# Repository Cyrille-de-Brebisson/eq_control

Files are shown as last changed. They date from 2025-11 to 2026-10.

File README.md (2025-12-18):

# eq_control

Eq control is an esp32/arduino based equatorial telescop mount controler system.
This also has an additional focuser controler (or rotator if you want, but focus is the most useful)

This system was originally designed for an EQ3, but has been sucessfully used on EQ5 and other az mounts.

It consist of a CPU that can control 3 stepper motors for RA, Dec and focus, a LCD and a keyboard.

It can be used "in hand" as an offline controler.
It can be connected to a computer with Ascom or Alpaca for more complex astro (like astro photography).
The controler is a 6x7x1.7cm box which does everything!

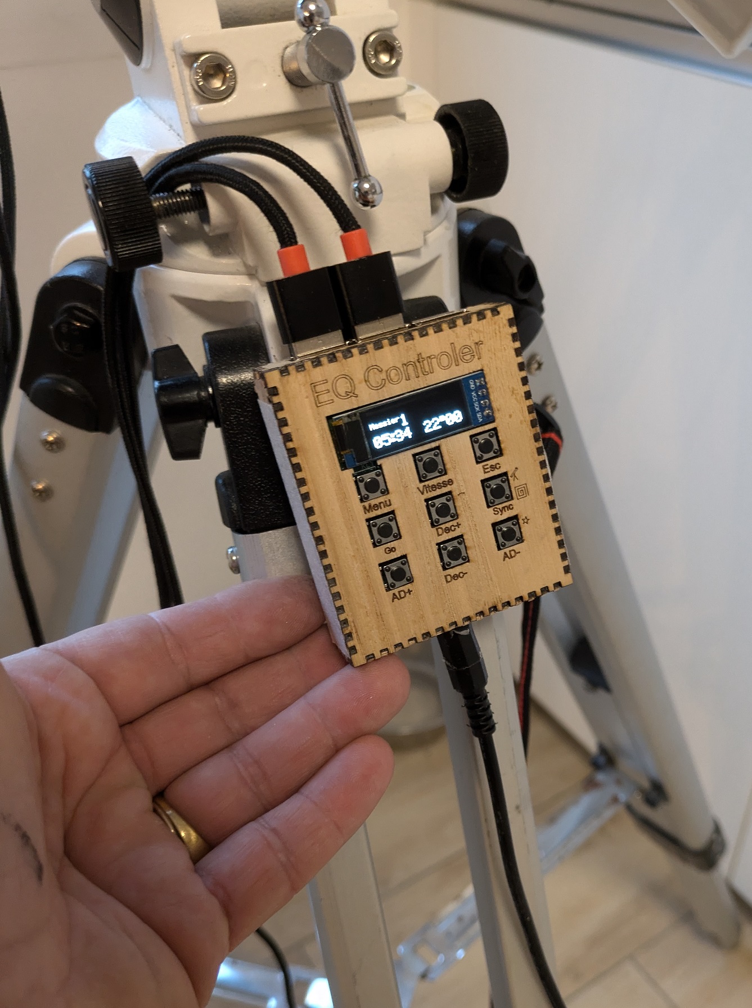
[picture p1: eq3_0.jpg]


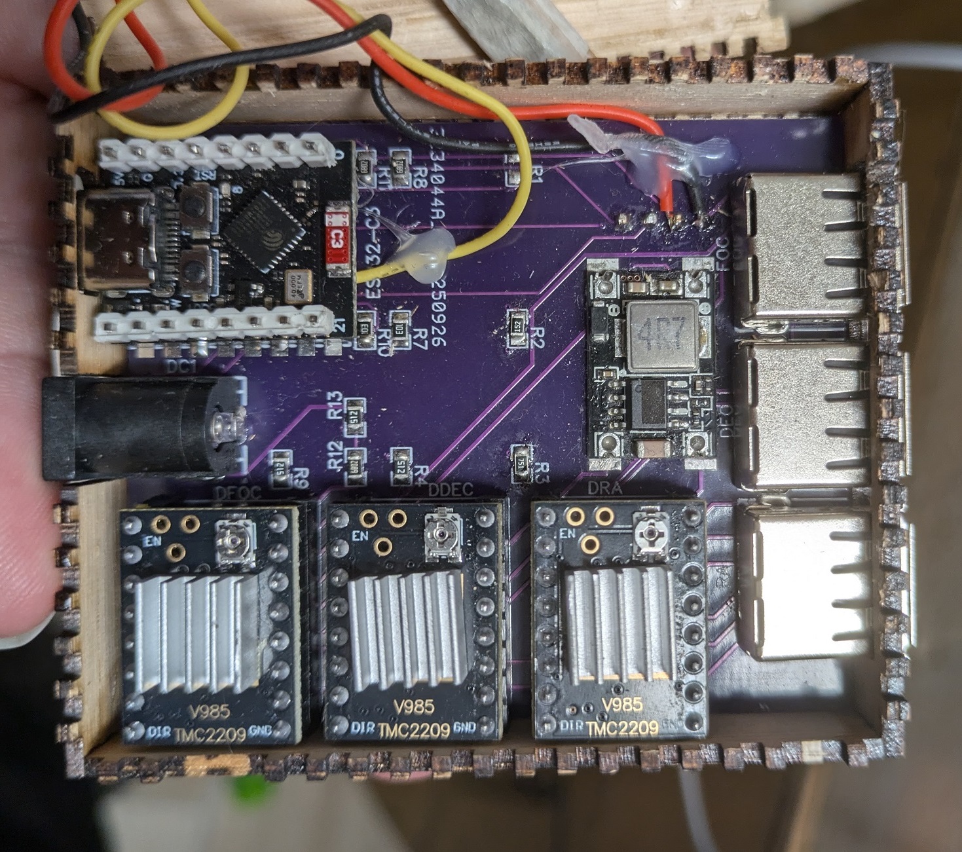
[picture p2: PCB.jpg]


# Brief history

This project started on arduino Nano. This was never released at large, but I have given a number of boards to various persons and I still own a number of them. As a result I need to continue supporting them.

Hence the code here continues support for these old boards which you will find in Firmware\eqControl_Ino

# Directory structure, Aka: Where to find stuff
## Software

If using esp32, you will open the Firmware directory using visual studio code and esp-idf. This uses the same .ino code as a #include!

in the Firmware\windows directory you will find a windows solution that uses once again the same code and can be used for debugging.

the Ascom directory contains the Ascom driver for the system (need visual studio and ascom tools installed)

## Hardware
HW project can be found here:  https://oshwlab.com/cyrille.de.brebisson/sheet_copy_copy_copy_copy_copy_copy_copy_copy

The Hwardware and mechanicals directory has the Gerber and schematics.
I still need to put the files for making the laser cut box

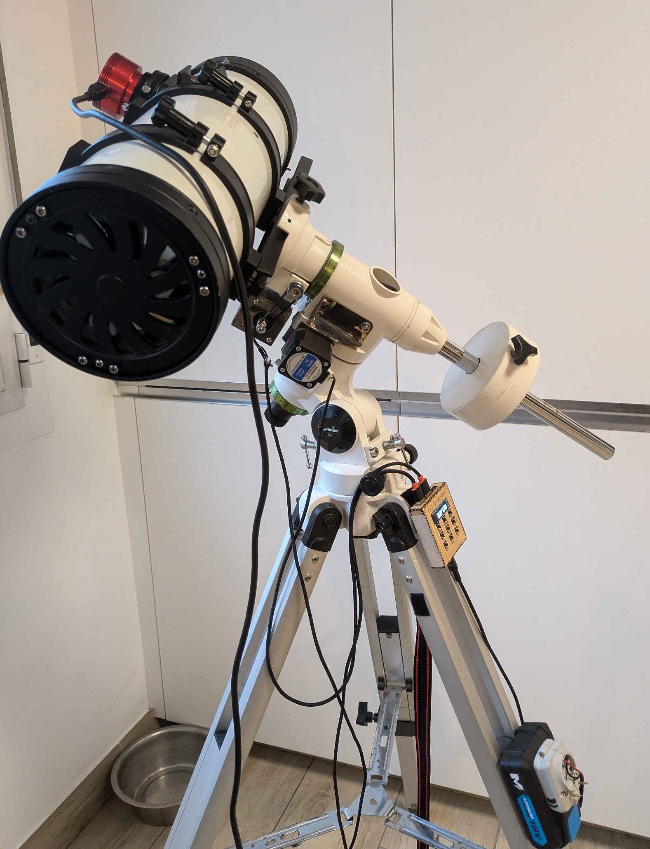
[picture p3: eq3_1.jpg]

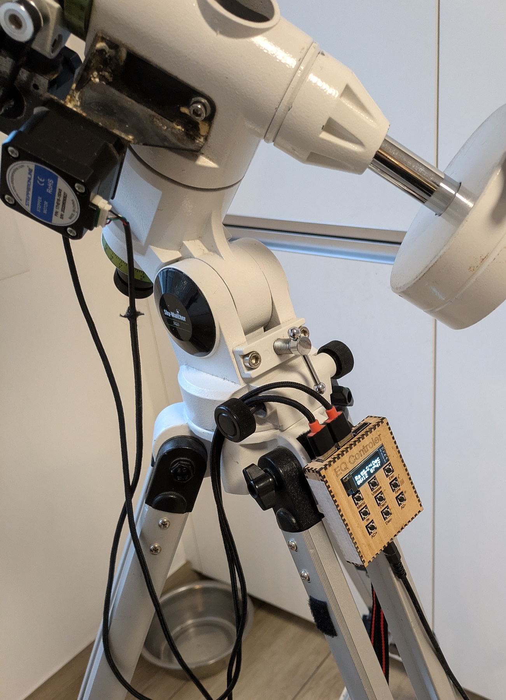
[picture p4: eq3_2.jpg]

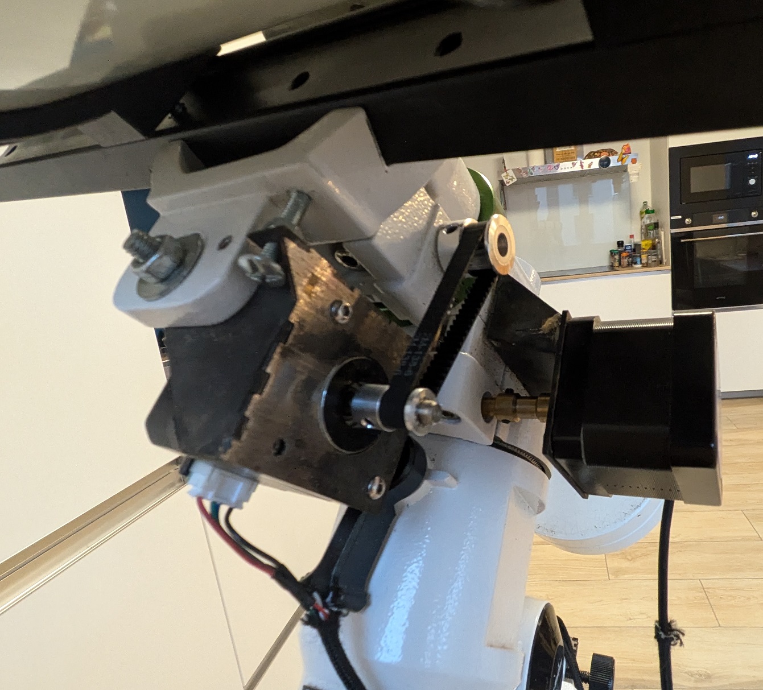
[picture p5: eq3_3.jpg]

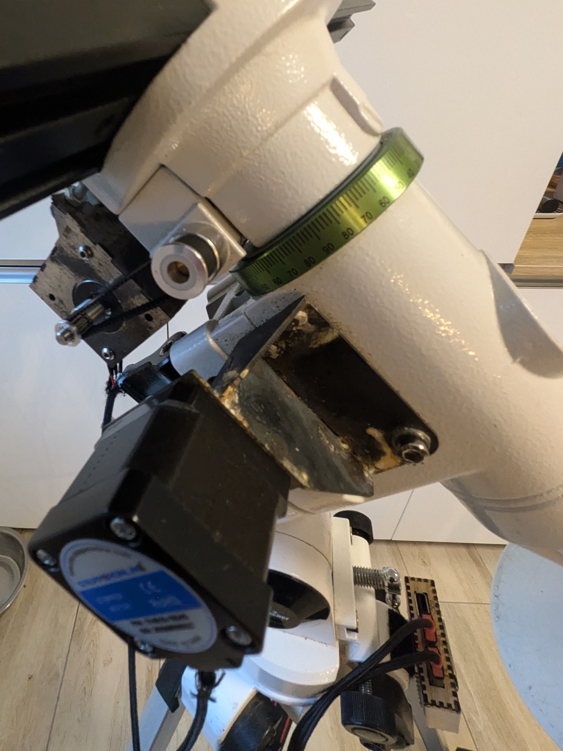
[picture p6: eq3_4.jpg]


# Licence
All content of this repository is copyright Cyrille de Brébisson
Contact me if you want to use all or part of it.
Most likely I will say yes unless it is for commercial use at which point... we can discuss

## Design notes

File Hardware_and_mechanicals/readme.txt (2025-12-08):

box esp32 files is a drawing for the "box" for the controler.
It is desinged to be laser cut out of 2mm thick wood or plastic.

eq3_5 dec.dxf is the declinaison motor holder for both EQ5 and EQ3. It is desinged to be laser cut out of 1.5mm thick metal. There is one bend to do, an "assembly" and a weld. Note that it is made as "one part" which will need to be separated in 2 at a tab as it reduces the costs for me here..

eq5ra.dxf is the eq5 ra motor holder. It also needs a "bend" and is also designed to be laser cut out of 1.5mm steel. Note that you will need to dril and tap 2 M4 holes in your mount to use it.

eq3_ra.svg is the EQ3 ra holder. Here again a bend and 3 peices to separate and place together.

PCB, schematics and Gerbers are the pure HW files.

About the HW design.

An esp32C3 super mini is the core.

The 9 key keyboard is read by the CPU using ADC and a resistance ladder due to the IO limitation.

The same ADC is used to read external power level using a divider bridge.

5V to ESP is provided using a DC-DC board for high power efficiency (regulator can drop significant power, especially if dropping from 20V to 5V).

3 TMC2209 stepper drivers are used to drive the motors. They are driven using the step pin and serial communication.

A 0.96 I²C OLED 128*32 LCD does the display (prefer blue, less agressive for the eyes)

Connection to the motors is done using USB2 connectors cause they are cheap and good connectors.
It is also easy to find USB cables, cut the device side and repurpose them for motor connection.

A 5.5x2.1 barrel connector is used for external power. Use a 12-15V, 1A power source or a 15V USB-C to barrel adaptor for power.

I usually place the ESP and drivers on low profile "carriages" to make them replacable in case of...

Appart from the drivers which are relatively expensive and for which you need 2 or 3, all the rest is dirt cheap. And the PCB will come as a 5 pack. So I advise that you take enough material to build at least 2 in case of!

Parts (all sourced on ali express)
Esp32C3 super mini board (<3 euros): https://fr.aliexpress.com/item/1005009776606859.html
9 6x6 low profile push buttons, SMT (<1 euro, usually by 20 packs): https://fr.aliexpress.com/item/1005003163947039.html
3 TMC2209 (~2.6 euros per driver): https://fr.aliexpress.com/item/1005009299841291.html
0.96 OLED 128*32 LCD (<2 euros): https://fr.aliexpress.com/item/1005008918700196.html
10k, 1.5k, 750R, 68K and 5.1K 0805 resistances will be needed (but yhou could probably get by without the 68K and 5.1K ones using 10k and 1.5k instead for the power divider bridge).: https://fr.aliexpress.com/item/1005004765509774.html
3x 100µF capacitors: https://fr.aliexpress.com/item/1005004506467517.html
header: Use low profiles ones! https://fr.aliexpress.com/item/1005004122312694.html
USB connectors (1.5euros by 10): https://fr.aliexpress.com/item/4001141222647.html
5.5 2.1 DC connecteor PCB: https://fr.aliexpress.com/item/32839712664.html

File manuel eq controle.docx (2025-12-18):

# Manuel d’utilisation « EQ Controleur »

Conceptions Cyrille.de.brebisson@gmail.com

## Introduction

L’EQ Controleur (contrôleur pour montures équatoriales, originellement EQ3 et EQ5, mais utilisable sur plein d’autres montures) a été conçu dans dans l’optique :

- De créer un contrôleur le plus simple possible à utiliser
- De créer un contrôleur par cher pour une EQ3
- De créer un contrôleur utilisable en mode manuel
- De créer un contrôleur permettant de faire de l’asto-photo

La première section de ce manuel assume que vous avec un EQ Controleur installé sur votre monture et désirez l’utiliser en mode manuel.

La deuxième section étudie les possibilités offertes si vous êtes connecté à un PC.

La troisième section explique la partie configuration.

## Utilisation « Manuelle »

### Démarrage

Sortez votre monture, alignez là (grossièrement) vers le nord. Utilisez une boussole (une vraie ou celle de votre portable), essayez de la mettre à la bonne inclinaison (selon votre latitude). Si c’est la nuit, vous pouvez vous aider d’un laser que vous insérez dans l’axe polaire et vous bougez la monture pour pointer Polaris.

Installez votre optique sur la monture et équilibrez-la en RA (Right Assention où ascension droite) et en DEC.

Pointez le télescope vers le nord avec le contrepoids « vertical ».

Branchez le contrôleur sur une alim entre 9 et 20V (12 à 15 est impec) 20W.

Notons que dorénavant je parlerais de 12V pour parler ce cette alimentation quel que soit la valeur réelle.

Il va s’allumer. Votre télescope est en mode suivit immédiatement.

### Mouvements basiques

Utilisez les touches dec+/dec- et ra+/ra- pour bouger le télescope.

Pressez la touche vitesse pour « cycler » entre les différentes vitesses possibles, de une minute d’arc par seconde a 4° par seconde. Apprenez la place de ces 5 touches « par cœur » car vous les utiliserez en regardant à l’oculaire !

Notez que l’affichage vous indique la position du télescope ainsi que la vitesse (en petit, désolé !)

Vous pouvez des à présent pointer le télescope sur un objet et le regarder…

Disons que l’objet en question est l’étoile Arcturus.

### Menu étoiles et synchronisation

Appuyez sur la touche « menu » jusqu’à ce que l’affichage indique :

Ou tout autre nom d’étoile précédé par ce « dessin » d’une étoile.

Utilisez les touches RA+/RA- et DEC+/DEC- pour « séléctionner » arcturus dans la lise. RA- passe à l’étoile suivante, RA+ à la précedente. Dec+/Dec- avancent de 10 en 10 permétant d’aller plus vite.

Selectionner Arcturus

Puis appuyez sur la touhce « Sync ». Vous venez d’apprendre au télescope « ou il est ».

Vous pouvez maintenant aller séléctionner une autre étoile, par example Vega, et appuyer sur la touche « Go » et le téléscope deverais se déplacer sur Vega !

Plus votre mise en station est correcte, plus Arcturus était bien centré dans votre oculaire et plus votre monture est bonne méchaniquement, plus ce déplacement sera correct et précis !

### Messier, Ngc et Cadwell

Vous avez probablement repéré en appuyant sur la touche menu que le système vous proposait d’autres options.

En effet, vous pouvez selectioner tout objet Messier, Cadwel et les 740 Ngc les plus visibles.

Comme les étoiles, ces objets sont utilisable pour « sychroniser » le télescope, où pour faire un goto (déplacer le télescope) de la même manière qu’avec les étoiles.

moins d’avoir un méga télescope, et dans ce cas que faites vous avec ce petit système tout simple, cela deveais largement sufire !

### Escape et spirale

2 autres touches sont importantes.

La touche Esc(ape) permet de ressortir d’un menu et de revenir à l’ecran principal.

Elle arréte aussi tout mouvement en cours du télescope.

La touche Sync, quand on est sur l’ecran pricipal vas faire décrire une spiralle (bon, une spirale carrée, c’était plus facile a programmer) au télescope. Notons que la vitesse et l’espacement entre les spirales vont être d’autant plus grandes que vous avez spécifié une grande vitesse. Cette touch est TRES utilie quand on est proche de l’objet convoité mais qu’il n’est pas dans l’oculaire.

Si c’est le cas, le centrer, retourner dans le menu associé et refair eun sync permet de « corriger » le télescope.

Si votre télescope n’est pas parfaitement mis en station, un « go » dans une région très différente résultera en un télescope qui peut être à quelques degrés de votre cible. Refaite un sync sur une étoile dans la zone et vous « recentrerez » le télescope dans cette zone.

### Planètes

Finissons par l’écran planètes qui est un peu plus compliqué.

En effet, pour pointer une planète, il faut savoir ou elle est, et pour ce faire, il faut connaitre la date. Mais le CPU n’a pas d’horloge, il vas donc falloir la lui indiquer !

Ici 01/01/23 (format J, M, A). Notez le 01 souligné.

Les touches RA+/RA- permettent de changer l’information soulignée. Les touches dec+/dec- permettent de changer la valeur. Sélectionnez donc la date du jour, puis séléctionnez la planette (toujours avec dec+/-). Utilisez les touches Sync et Go comme avec les étoiles et autres objets pour synchroniser le telescope ou aller sur l’objet.

Note : Je n’ai jamais bien testé cette partie du soft et je ne connais pas la précision réele de mes calculs ! à utiliser en faisant attention !

### Note sur le retournement au méridien

Une monture equatoriale alemande doit changer le télescope de coté lorsque sa dirrection de visée traverse le méridien.

Généralement vous verrez ce mouvement « bizard » lors des operations de « aller vers », ou goto. Mais si vous observez un objet longtemps, le télescope peu effectuer ce retournement par lui-même. Ce retrounement arrive lorsque l’axe télescope-contre-poid dépasse l’horizontale.

Pour que ce retournement se passe bien, il faut que le télescope sache ou est l’horizontale de l’axe télescope-contre-poid (axe RA). C’est pour cela qu’il est important de démarrer le télescope avec cet axe pointant « vers le bas », car le système se « souviens » de cette position pour savoir ou se trouve l’horizontale.

C’est pour cela qu’il est important de ne pas faire de mouvement en RA en bougant le télescope en desserant les freins, mais de toujours utiliser la raquette.

### Touches spéciales

Maintenir la touche Esc pressée, puis appuyer sur la touche RA- (en bas a droite) à pour effet de changer la vitesse de suivit sidérale. Le système supporte les vitesses Sidérales, Lunaires, Soleil et King. Chaque appui sur RA- avance d’un cran.

Maintenir la touche Esc pressée, puis appuyer sur la touche GO reset l’écran. A utiliser si l’affichage plante.

Maintenir la touche Esc pressée, puis appuyer sur la touche RA+ (en bas a gauche) reboot le système. Attention, le télescope pense alors être en position de départ !

Maintenir la touche Esc pressée, puis appuyer sur la touche dec+ desactive le retournement au méridien. A utiliser avec parsimonie et en faisant attention.

Maintenir la touche Esc pressée, puis appuyer sur la touche Sync à pour effet de changer la dirrection de l’axe delta. Si il y a eu un problème d’initialisation cela peux résoudre ce problème. Mais sinon vous ne devriez pas à avoir a utiliser cette combo.

### Derniers détails

L’écran de base indique les coordonées RA/DEC actuelles.

Il indique aussi la vitesse (Spd) de déplacement que vous savez maintenant changer.

Il indique la vitesse de suivit. Ici Sidéral. Que vous savez aussi changer !

Le dessin a coté de la vitesse indique si le telescope est a l’est ou a l’ouest de la monture. Notez que vous retrouverez ce dessin dans les selections d’objets type Messier, Ngc… Si il est affiché, cela indique que l’objet en question est de l’autre coté du méridien par raport a la position actuelle du télescope.

Pour finir si la vitesse est « barrée », cela indique que la monture n’est pas allimentée en 12V, mais seulement via la prise USB, ce qui n’est pas suffisant pour faire bouger les moteurs !

## Utilisation assistée par ordinateur

C’est une fois connectée à un ordinateur que le système montre toute sa puissance.

### Connection filaire, driver Ascom

Il y a 2 connections possibles, la connexion filaire (conseillée car plus stable), MAIS qui est de temps en temps problématique.

En effet la connexion USB est souvent mal faite sur les ordinateurs. Et quand on alimente la monture en 12V, il se peut que le 0V (masse) de l’alimentation ne soit pas équivalent au 0V de l’USB. Mais sur la raquette, les 2 0V sont les mêmes. Sur certains ordinateurs cela peut poser problème. De temps en temps l’ordre de connexion change les choses. Soit il faut d’abord connecter le 12V, puis l’USB, soit dans le sens inverse. Ecoutez le PC et les « bit bip » de connexion USB pour avoir une bonne idée de ce qui se passe.

### Installation Ascom

Il va vous falloir installer le logiciel, Vous allez devoir installer le système Ascom, puis copier les 4 fichiers ASCOM.BrebissonV1.exe, issposdll.dll iss.wav et power.wav dans le répertoire C:\Program Files (x86)\Common Files\ASCOM Puis, ouvrerez une invite ligne de commande (touche windows +R, tapez cmd, enter), aller dans le répertoire ascom en tapant « cd " C:\Program Files (x86)\Common Files\ASCOM" » enter

Puis taper : « ASCOM.BrebissonV1 /register »

Cela à pour effet d’enregistrer ce programme dans le système Ascom.

Accessoirement, vous pouvez cliquer sur le fichier install.bat après avoir dézipé les fichiers dans un repertoire temporaire.

Lancer ASCOM.BrebissonV1.exe et vous verrez la fenètre qui est quelques pages plus loin.

### Connection « com »

La première chose à faire vas être de « connecter » le programme a votre raquette que vous aurez branché sur votre ordinateur via le port USB. Cela se fait via ce que l’on appelle un port « com ».

Dans tous les cas il va vous falloir « trouver » quel est le port COM utilisé par votre raquette.

Si le logiciel de contrôle à été lancé APRES que vous ayez connecté la raquette au PC, il va vous falloir appuyer sur le bouton « scan coms » pour recréer la liste des ports com qui est affiché à gauche du dit bouton. Mon conseil est de regarder la liste, de scanner les coms, et de re-regarder la liste. Le « nouveau » com est celui de votre raquette !

Si le logiciel à été lancé avant… vous pouvez essayer les divers coms, ou alors déconnecter votre raquette, rescanner la liste et procéder comme indiqué ci-dessus.

Puis appuyer sur le bouton « connect » qui deviens alors « disconnect » pour que le programme commence à parler à la raquette…

### La fenêtre principale

S’affiche la position actuelle du système. Notons que dans les premières versions la raquette vas redémarrer et perdre sa position ! Si le télescope était en position « nord », le PC qui connais l’heure locale vas, en utilisant les données de positions indiquées dans le setup calculer la position en AD automatiquement. Si votre télescope est parfaitement aligné en position nord, vous êtes donc a peu près synchronisé.

La partie « mount » indique la position actuelle. La touche Copy vas la copier dans les 2 boites d’édition dessous qui permettent de faire un goto ou sync.

Les touches goto et sync permettent de faire un goto ou sync à la position indiquée dans les 2 boites de texte sous la position actuelle.

Le bouton stop arête tout mouvement du télescope.

« Mount East »/ « Mount West » correspond à l’appui sur les touches Esc puis Sync de la raquette. Cela change la dirrection de l’axe delta. Si il y a eu un problème d’initialisation cela peux résoudre ce problème.

Le bouton flip enable/flip disable permet d’arrêter le retournement au méridien. Cela fait que le télescope peu se retrouver la tête en bas ! A utiliser quand vous savez ce que vous faites !

Notons l’indication « flip in : 6 :23 » qui indique qu’il reste 6h23 minutes avant un retournement au méridien (si le télescope reste pointé sur le même objet).

Dessous, vous avez une drop box qui indique la vitesse de déplacement sidéral.

Vers la droite, 4 touches permettent de bouger le télescope à la vitesse indiquer juste au-dessus.

En bas de la zone, Park/unPark permet de « parker » la monture, c’est-à-dire de la remettre en position « nord » et d’arrêter le mouvement sidéral. Unpark se contente de relancer le mouvement sidéral.

Flip force un retournement au méridien. A utiliser quand le télescope est en bout de course pour forcer les choses a un moment opportun pour vous.

isNorth vas « assumer » que le télescope pointe au nord et forcer les coordonnées correctement.

Et finalement les boutons +90° et -90° permettent de forcer la monture a faire 90° en plus ou moins en RA. C’est très utile lors de la mise en station avec sharpcap ou il faut faire décrire 90° au télescope !

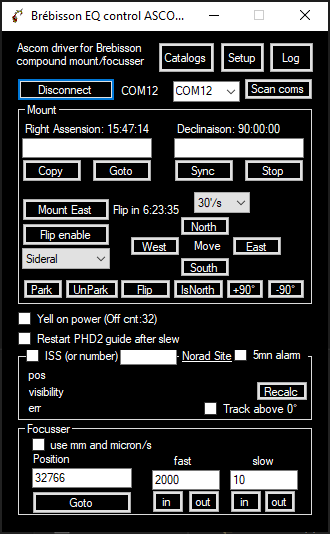
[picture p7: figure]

Le checkmark « Yell on power” vas faire que le programme va jouer le fichier son « power.wav » si il détecte une perte de 12V. Très utilise si on est en nomade sur batteries.

Le checkmark « Restart PHD2 guide after slew” vas faire que PHD2, si il est actif vas être relancé en mode guidage après une opération de goto. Comme PHD2 s’arrête lorsqu’il détecté un mouvement de télescope, cela permet de le relancer automatiquement si votre logiciel de prise de vue ne le fait pas.

### La section ISS !

Sélectionner ISS et le système va se connecter au site du Norad (oui, comme dans WarGames !) et récupérer les données orbitales de l’ISS (ou de tout autre satellite dont vous indiquerez le numéro dans la zone d’édition a côté de ISS. Cliquer sur « Norad site » pour rendre visite au site du Norad et trouver les infos sur les satellites.

Sélectionner 5mn alam pour avoir ma jolie voix vous indiquer que l’ISS vas arriver 5mn avant qu’elle ne dépasse l’horizon.

Vous allez ensuite voir la position de l’ISS en ra/de cet az/alt, suivit d’une indication « NotVisible » (pas visible) et le temps a attendre avant qu’elle ne passe au-dessus de l’horizon. Vous aurez aussi l’indication de la « hauteur » du transit (ici 19°, pas très haut), de la durée (9mn) et de la vitesse max (ici 0.8° / s).

Notons que si le système ne peut pas se connecter au Norad car la ligne est occupée par Matthew Broderick, il utilisera les dernières infos connues.

Sélectionner « Track above 0° » et le système vas suivre l’ISS des qu’elle sera au-dessus de l’horizon !

Pour que cela marche bien il faux mieux préparer le télescope quelques minutes avant (d’où l’alarme). Placez le environ 20° au-dessus de l’horizon dans la zone ou l’ISS vas arriver, faite une synchronisation sur la position pour être le plus précis possible (si vous le faites trop bas la réfraction atmosphérique peux troubler les choses). Puis descendre le télescope proche de l’horizon et attendre.

Quand l’ISS deviens visible, et que vous êtes en mode « track » vous aurez cet écran-là :

La partie importante est la zone d’édition indiquant « Press up/down/right/left to correct. » cliquer dedans et utiliser les touches haut/bas/droite/gauche de votre ordinateur pour envoyer des corrections supplémentaires au système. Cela vous permet de corriger manuellement toute erreur de position.

Le système va tracker l’ISS (ou le satellite) tant qu’il le peut.

Notons que si le satellite va trop vite, il n’y arrivera pas (mais il essayera), plus le satellite sera près du zénith plus il ira vite. LA monture arrivera probablement au méridien a un moment et voudra se retourner ! Si elle y arrive assez vite, elle continuera à tracker… La correction en arc seconde sera indiquée pour info.

Quand vous de-cliquez le bouton track, un log des positions sera ajouté sur le desktop.

### La section Focusser

Ici vous pouvez utiliser l’option focus du contrôleur. En effet ce système est capable, en plus du télescope de contrôler le focus de votre optique si elle est motorisée.

Le checkmark « Use mm and micron” indique si vous voulez travailler en pas, ou en distances réelles.

La position indique la position actuelle en pas (toujours positive) ou en mm (positive ou négative).

Les boutons in/out fast et slow permettent de faire bouger le focusser a une vitesse donnée en pas ou microns par secondes.

## La section setup

Cliquer sur le bouton « Setup » pour entrer dans la section de configuration.

Vous y trouverez les informations sur l’observatoire. Ces infos sont principalement informative et seront utilisé par le logiciel de capture d’image pour régler le plate solve et pour tagger vos photos. La longitude sera utilisée par ce logiciel pour calculer l’heure sidérale (important).

Vous allez ensuite trouver 3 zone similaire des configurations des moteurs pas à pas. Dans tous les cas il va falloir indiquer le nombre de pas maximum, qui correspondront a un tour complet dans le cas des moteurs RA/DEC et de l’amplitude max pour le focusser (notons que celui-ci est limité a 65535 pas).

Il faudra indiquer le nombre de pas max par seconde (la vitesse max en gros) et le temps d’accélération pour arriver a cette vitesse max en ms.

Il vous est aussi possible d’indiquer un baklash. C’est-à-dire un nombre de pas ou d’arc secondes a rajouter sur tout mouvement quant on inverse la direction de mouvement. Cela permet de gérer les jeux mécaniques.

Vous pouvez aussi indiquer le ‘sens’ du moteur via la ckechbox ‘invert’.

Dans le cas du focus, si vous indiquer la taille d’un pas en microns, cela permettra aux meilleurs soft astro (genre Prism) de gérer les choses en mm ce qui peut être très pratique dans certains cas (par exemple los de l’ajout d’un filtre).

Dans le cas du mouvement en RA, vous pouvez indiquer l’amplitude en °. 180° signifie que l’axe RA ne dépassera jamais l’horizontale. Dans la réalité, il est généralement utilisé de permettre un mouvement de 30 minutes à 1h de plus de chaque côté de l’horizontale. 30 minutes de RA étant 7.5°, ajoutons 2*7.5=15° a 180 pour 195°.

Notons la présence d’une aide au calcul de pas en bas. C’est juste une suite de multiplication et de divisions qui vous évite d’avoir à sortir la calculatrice !

Les drivers de type DRV2209 qui équipent mes dernières montures sont en 256 micros pas. La plupart de moteurs pas à pas sont en 200 pas par tours, les EQ3 ont une réduction mécanique de 130 :1 en RA et 65 :1 en dec. Les EQ5 144 :1 sur les 2 axes. Si vous avez des poulies, il va falloir les rajouter via les ‘gear’. Pour finir il y a une division qui permet de calculer la vitesse en pas/s selon ce que vous désirez, et ce que votre monture supporte.

La section guiding permet de configurer le guidage. Donnez la vitesse de guidate en arc" par seconde de contrôle. J’ai ajouté des options pour moduler le contrôle du logiciel de guidage ‘agresivity, qui se multiple a la consigne), pier invert qui inverse la consigne suivant le coté du télescope, invert qui inverse la consigne tout le temps et stop qui bloque le guidage sur un axe. Mais normalement il n’uy a pas lieux d’utiliser ces choses que j’ai ajouté principalement pour faire mes tests..

La section « Time base » est une analyse de la différence entre la théorie et la pratique. Il va analyser la manière dont la raquette et le PC perçoivent le temps et vas permettre (en assumant que le PC est correct) de calculer une correction (en cliquant sur le bouton Auto). Laisser tourner le système au moins 5 minutes avant d’utiliser cette fonction !

On y voit la base de temps PC, la base de temps HW et la différence. On y voit aussi le nombre de pas par seconde en sidéral « envoyés » par le HW et l’erreur.

Les arduinos ont généralement un drift non négligeable. Mais les ESP32 sont très bon et n’ont pas besoin de correction.

Les ESP32 ont un réglage de wifi.

Vous pouvez sélectionner le mode AccessPoint (la raquette est un server wifi), ou « client » ou il se connecte à votre réseau wifi. Indiquez le nom du réseau et le mot de passe. L’adresse IP vous sera indique ici aussi.

Pour finir le bouton « save in HW » vas « écrire » toutes les données dans la raquette (et faire un reboot). Reload from HW permet de recharger les données qui sont dans la raquette si vous avez changé un truc et que vous voulez revenir à la vraie valeur.

Save conf et load conf permettent de sauvegarder une configuration sur PC.

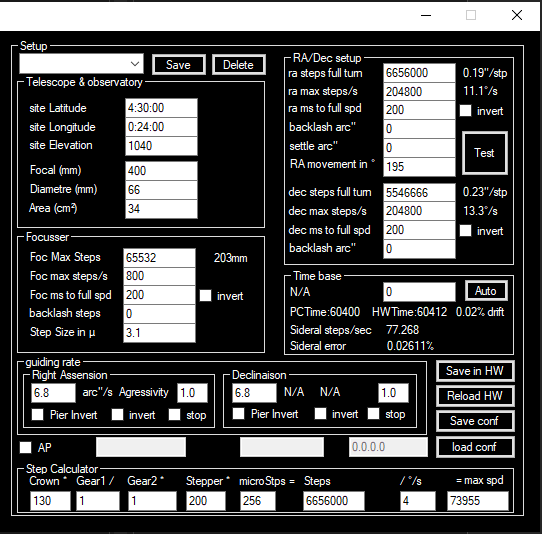
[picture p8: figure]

## La fenêtre Catalogs

Bone encore une chose à moitié faite….

Cliquer sur Messier, Cadwell, Ngs, Stars et planètes pour afficher à droite la liste en question. Sélectionner un des objets et cliquer sur GoTo ou Sync pour faire un Goto ou un Sync. C’est une version ordinateur des menus équivalents de la raquette.

L’écran montre la position du télescope sur la voute céleste. Vous pouvez bouger la vue avec la sourie, et si vous sélectionnez un objet dans cet ecran et qu’il apparait en bas de l’écran, les touches goto et sync permettent les actions habituelles.

Le bouton « OnScope » recentre la vue sur le télescope.

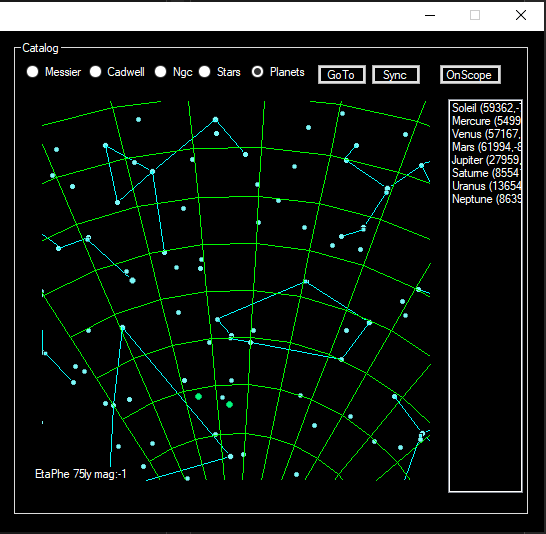
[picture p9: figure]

## La fenêtre « log »

Cliquer sur Log pour voir la fenêtre le log. Vous y trouverez principalement un log de tout ce qui c’est passé au sein de la monture. Les check box « show system », « show ascom »… etc permettent d’ignorer certains évènement qui ne vous intéressent pas.

2 lignes de texte montrent les communications entre la monture et le PC en hexa et en « clair » et permettent de faire un freeze des choses pour étudier les choses en détail (principalement pour faire du débug).

Les 4 touches « pulse guide » permettent d’envoyer des pulsations de guidage. C’est utile pour tester le backlash de la monture de jour sur une cible fixe.

La section moteur indique la position des moteurs en pas et en % de mouvement.

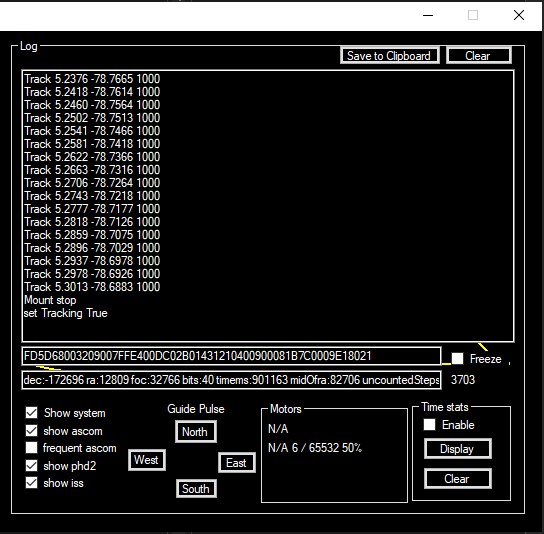
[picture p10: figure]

## Liaison avec Stelarium

Comme ce programme est un driver Ascom il est utilisable pour connecter votre télescope a tout logiciel gérant Ascom tel que Prism, SharpCap, Stellarium ou PHD2.

Je me contenterais d’expliquer l’utilisation dans Stellarium qui est assez complexe tout en étant super utile pour un débutant.

Premièrement, lancer le plugin contrôle télescope. F2 ou configuration window/ Plugins, telescope control (ou controle de telescope), sélectionner « lancer au démarrage). Redémarer stellarium.

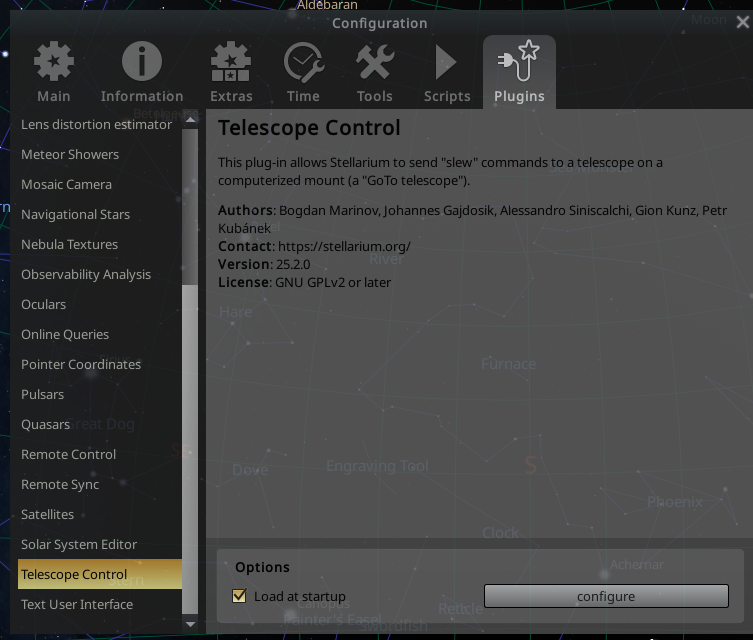
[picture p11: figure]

Cliquer sur ‘contrôle télescope’ qui est maintenant dans la barre d’actoin en bas. « configure telescope » Add new telescope , Ascom, choose ascom telescope, et séléctionner Ascom telecope driver pour BrebissonV1.

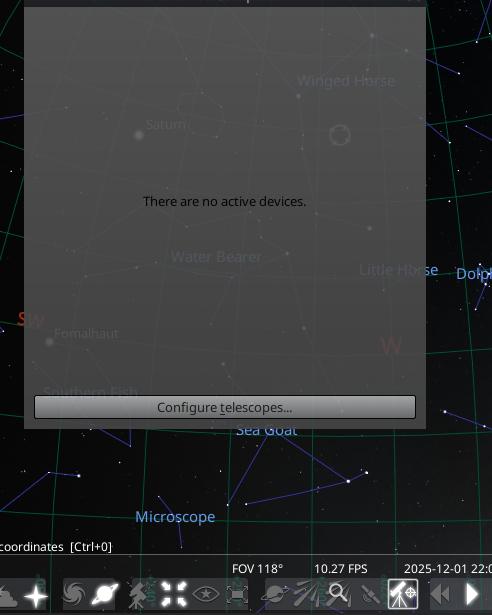
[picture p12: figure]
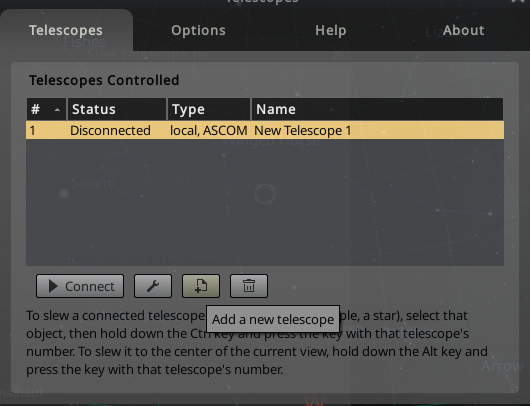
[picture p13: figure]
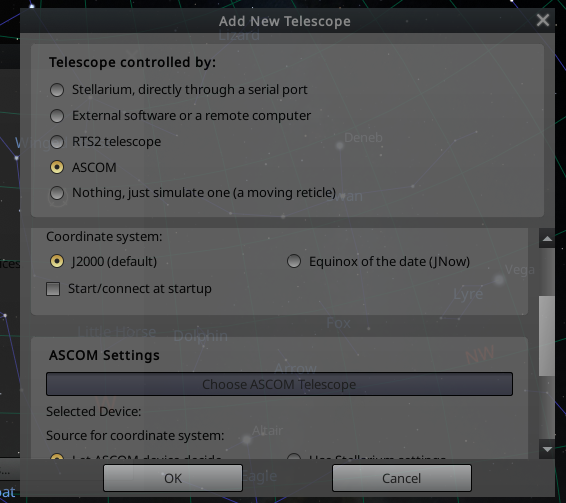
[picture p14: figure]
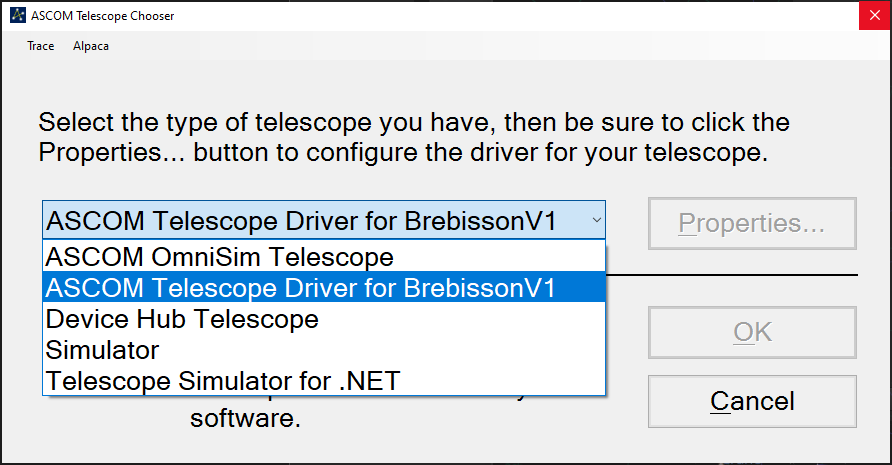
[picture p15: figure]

Connecter le telescope et vous allez voir l’UI suivante : Stellarium montre ou pointe le télescope avec le réticule. Et la boite de dialogue permet de pointer le télescope. Pour se faire, sélectionner un objet dans stellarium en cliquant dessus, puis cliquer sur « current objetct » dans la boite de contrôle du télescope, puis « Slew » pour faire un Goto. Sync permet de synchroniser. L’interface est un peu bizarre mais marche.

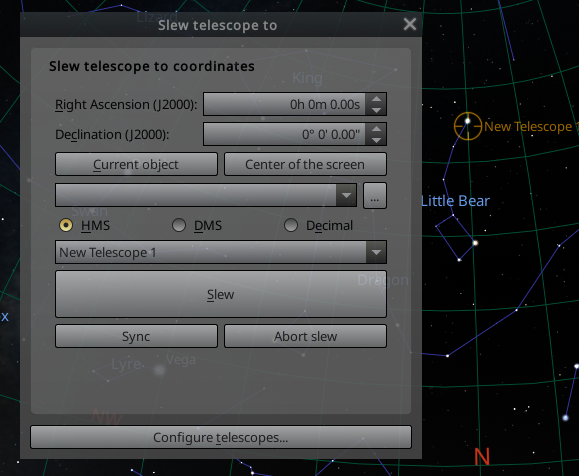
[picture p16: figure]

## Liaison avec SharpCap

Si votre télescope a une caméra vous pouvez utiliser Sharpcap pour synchroniser.

Dans Fichier, SharpCap settings, Hardware, section « mount », séléctionner “Ascom Telescope driver for BrebissonV1”. Note, vous pouvez aussi connecter le focusser!

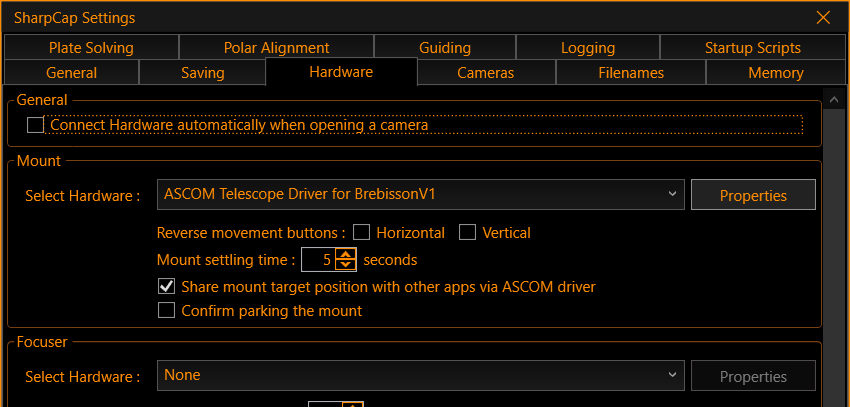
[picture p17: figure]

Conencter la camera puis assurez vous que la monture est connéctée :

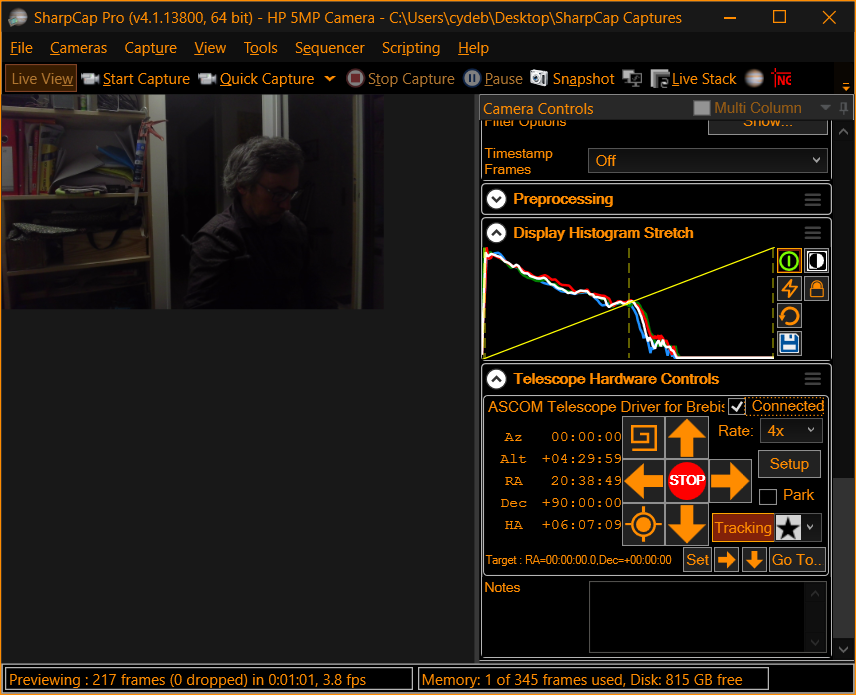
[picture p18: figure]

Prenez une photo des étoiles (pas de moi), et utiliser le menu « tools, plate solve and resync » pour que sharpcap fasse un plate solving et synchronize la monture.

## Liaison Alpaca (esp32 seulement)

Alpaca est le nouveau système de connexion Ascom qui utilise le réseau.

Pour utiliser Alpaca, votre raquette devra être sur le réseau de votre ordinateur. Soit via une borne wifi « générale », ou connecté a votre PC, ou en mode « serveur » ou c’est la raquette qui sert de borne wifi.

Dans les 2 cas la configuration se fait via le programme driver Ascom normal via la ligne ou on spécifie le réseau wifi. En mode AP (Access Point), la raquette se comporte comme une borne wifi et vous devrez y connecter votre ordinateur. Dans l’autre cas c’est la raquette qui essayera de se connecter au réseau. Utiliser le même nom dans les 2 cas simplifie bien les choses !

Sur la raquette l’interface suivant apparaitra après l’interface focusser. Elle indique l’adresse IP de la raquette (ici 0.0.0.0 en mode test), et le nom du réseau (ici blanc car je suis en mode test). Vous pouvez utiliser les touches haut/bas pour passer du mode AP au mode station (attention, il vas y avoir un reboot du système).

Normalement sharpcap et autres programmes Ascom pourront alors se connecter a la raquette.

Mais vous pouvez aussi vous connecter via un browser internet a http://x.x.x.x/setup ou les x sont remplacé par l’adresse ip de la raquette.

Cela vous donnera access aux fonctions de base du système.

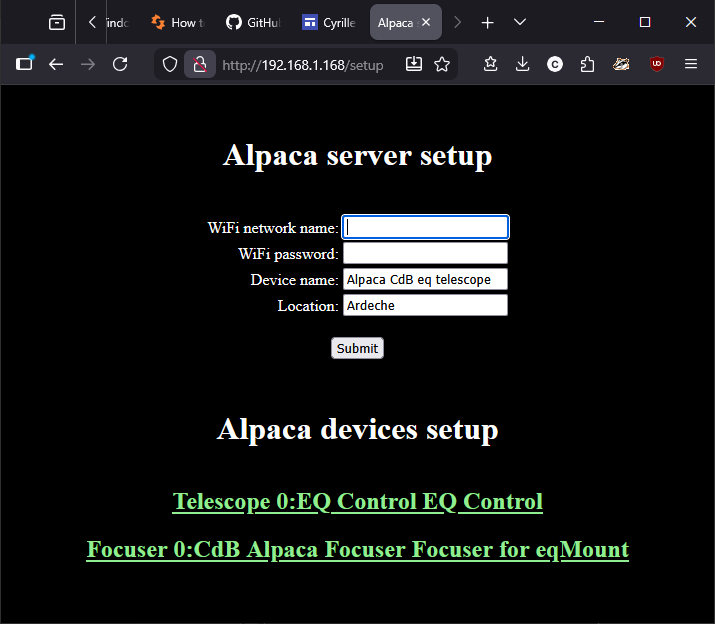
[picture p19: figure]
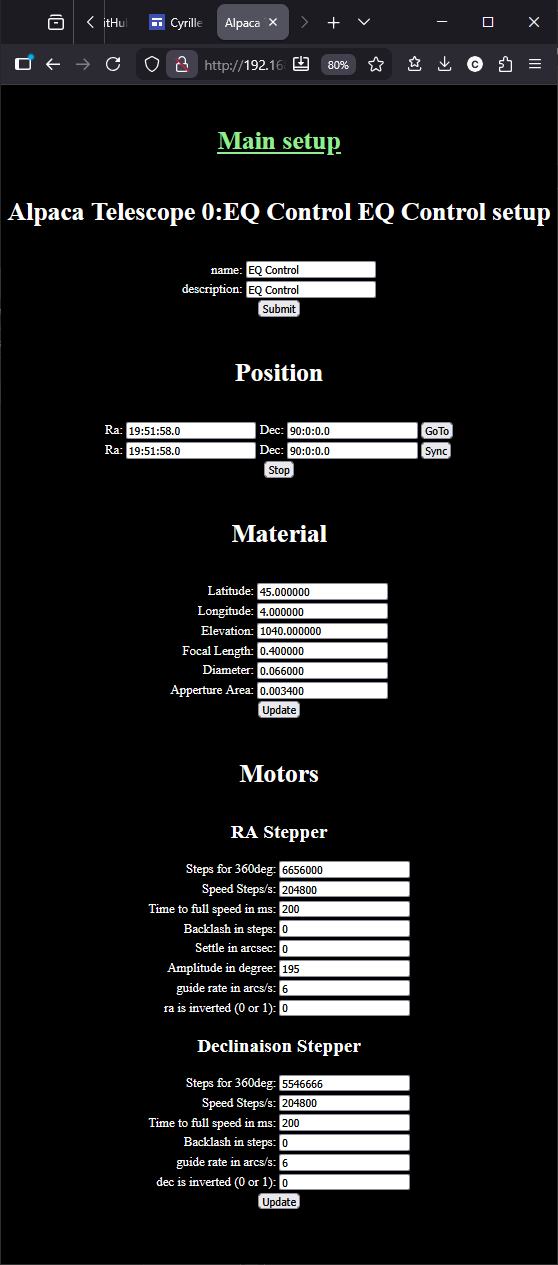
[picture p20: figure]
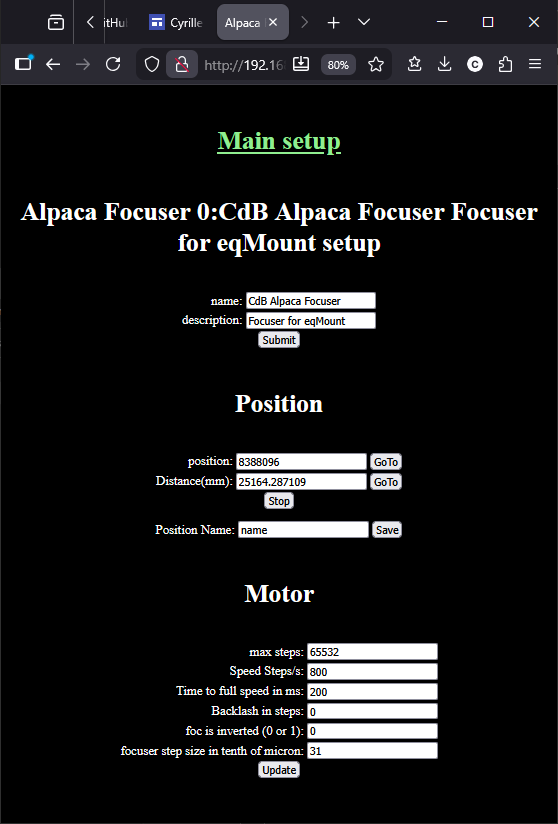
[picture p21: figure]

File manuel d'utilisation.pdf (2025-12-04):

# Manuel d’utilisation « EQ Controleur »

Conceptions Cyrille.de.brebisson@gmail.com

## Introduction

L’EQ Controleur (contrôleur pour montures équatoriales, originellement EQ3 et EQ5, mais utilisable sur plein d’autres montures) a été conçu dans dans l’optique :
- De créer un contrôleur le plus simple possible à utiliser
- De créer un contrôleur par cher pour une EQ3
- De créer un contrôleur utilisable en mode manuel
- De créer un contrôleur permettant de faire de l’asto-photo
La première section de ce manuel assume que vous avec un EQ Controleur installé sur votre monture et désirez l’utiliser en mode manuel.
La deuxième section étudie les possibilités oertes si vous êtes connecté à un PC.
La troisième section explique la partie configuration.

## Utilisation « Manuelle »

### Démarrage

Sortez votre monture, alignez là (grossièrement) vers le nord. Utilisez une boussole (une vraie ou celle de votre portable), essayez de la mettre à la bonne inclinaison (selon votre latitude). Si c’est la nuit, vous pouvez vous aider d’un laser que vous insérez dans l’axe polaire et vous bougez la monture pour pointer Polaris.
Installez votre optique sur la monture et équilibrez-la en RA (Right Assention où ascension droite) et en DEC.
Pointez le télescope vers le nord avec le contrepoids « vertical ».

Branchez le contrôleur sur une alim entre 9 et 20V (12 à 15 est impec) 20W.
Notons que dorénavant je parlerais de 12V pour parler ce cette alimentation quel que soit la valeur réelle.
Il va s’allumer. Votre télescope est en mode suivit immédiatement.

### Mouvements basiques

Utilisez les touches dec+/dec- et ra+/ra- pour bouger le télescope.

Pressez la touche vitesse pour « cycler » entre les diérentes vitesses possibles, de une minute d’arc par seconde a 4° par seconde. Apprenez la place de ces 5 touches « par cœur » car vous les utiliserez en regardant à l’oculaire !
Notez que l’aichage vous indique la position du télescope ainsi que la vitesse (en petit, désolé !)
Vous pouvez des à présent pointer le télescope sur un objet et le regarder…
Disons que l’objet en question est l’étoile Arcturus.

### Menu étoiles et synchronisation

Appuyez sur la touche « menu » jusqu’à ce que l’aichage indique :

Ou tout autre nom d’étoile précédé par ce « dessin » d’une étoile.
Utilisez les touches RA+/RA- et DEC+/DEC- pour « séléctionner » arcturus dans la lise. RA- passe à l’étoile suivante, RA+ à la précedente. Dec+/Dec- avancent de 10 en 10 permétant d’aller plus vite.
Selectionner Arcturus

Puis appuyez sur la touhce « Sync ». Vous venez d’apprendre au télescope « ou il est ». Vous pouvez maintenant aller séléctionner une autre étoile, par example Vega, et appuyer sur la touche « Go » et le téléscope deverais se déplacer sur Vega !
Plus votre mise en station est correcte, plus Arcturus était bien centré dans votre oculaire et plus votre monture est bonne méchaniquement, plus ce déplacement sera correct et précis !

### Messier, Ngc et Cadwell

Vous avez probablement repéré en appuyant sur la touche menu que le système vous proposait d’autres options.
En eet, vous pouvez selectioner tout objet Messier, Cadwel et les 740 Ngc les plus visibles.

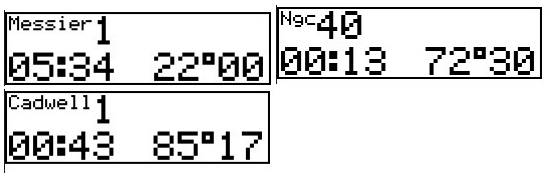
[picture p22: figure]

Comme les étoiles, ces objets sont utilisable pour « sychroniser » le télescope, où pour faire un goto (déplacer le télescope) de la même manière qu’avec les étoiles.
moins d’avoir un méga télescope, et dans ce cas que faites vous avec ce petit système tout simple, cela deveais largement sufire !

### Escape et spirale

2 autres touches sont importantes.
La touche Esc(ape) permet de ressortir d’un menu et de revenir à l’ecran principal. Elle arréte aussi tout mouvement en cours du télescope.
La touche Sync, quand on est sur l’ecran pricipal vas faire décrire une spiralle (bon, une spirale carrée, c’était plus facile a programmer) au télescope. Notons que la vitesse et l’espacement entre les spirales vont être d’autant plus grandes que vous avez spécifié une grande vitesse. Cette touch est TRES utilie quand on est proche de l’objet convoité mais qu’il n’est pas dans l’oculaire.
Si c’est le cas, le centrer, retourner dans le menu associé et refair eun sync permet de « corriger » le télescope.
Si votre télescope n’est pas parfaitement mis en station, un « go » dans une région très diérente résultera en un télescope qui peut être à quelques degrés de votre cible. Refaite un sync sur une étoile dans la zone et vous « recentrerez » le télescope dans cette zone.

### Planètes

Finissons par l’écran planètes qui est un peu plus compliqué.

En eet, pour pointer une planète, il faut savoir ou elle est, et pour ce faire, il faut connaitre la date. Mais le CPU n’a pas d’horloge, il vas donc falloir la lui indiquer ! Ici 01/01/23 (format J, M, A). Notez le 01 souligné.

Les touches RA+/RA- permettent de changer l’information soulignée. Les touches dec+/dec- permettent de changer la valeur. Sélectionnez donc la date du jour, puis séléctionnez la planette (toujours avec dec+/-). Utilisez les touches Sync et Go comme avec les étoiles et autres objets pour synchroniser le telescope ou aller sur l’objet. Note : Je n’ai jamais bien testé cette partie du soft et je ne connais pas la précision réele de mes calculs ! à utiliser en faisant attention !

### Note sur le retournement au méridien

Une monture equatoriale alemande doit changer le télescope de coté lorsque sa dirrection de visée traverse le méridien.
Généralement vous verrez ce mouvement « bizard » lors des operations de « aller vers », ou goto. Mais si vous observez un objet longtemps, le télescope peu eectuer ce retournement par lui-même. Ce retrounement arrive lorsque l’axe télescope-contre-poid dépasse l’horizontale.
Pour que ce retournement se passe bien, il faut que le télescope sache ou est l’horizontale de l’axe télescope-contre-poid (axe RA). C’est pour cela qu’il est important de démarrer le télescope avec cet axe pointant « vers le bas », car le système se
« souviens » de cette position pour savoir ou se trouve l’horizontale.
C’est pour cela qu’il est important de ne pas faire de mouvement en RA en bougant le télescope en desserant les freins, mais de toujours utiliser la raquette.

### Touches spéciales

Maintenir la touche Esc pressée, puis appuyer sur la touche RA- (en bas a droite) à pour eet de changer la vitesse de suivit sidérale. Le système supporte les vitesses Sidérales, Lunaires, Soleil et King. Chaque appui sur RA- avance d’un cran.
Maintenir la touche Esc pressée, puis appuyer sur la touche GO reset l’écran. A utiliser si l’aichage plante.
Maintenir la touche Esc pressée, puis appuyer sur la touche RA+ (en bas a gauche) reboot le système. Attention, le télescope pense alors être en position de départ !

Maintenir la touche Esc pressée, puis appuyer sur la touche dec+ desactive le retournement au méridien. A utiliser avec parsimonie et en faisant attention. Maintenir la touche Esc pressée, puis appuyer sur la touche Sync à pour eet de changer la dirrection de l’axe delta. Si il y a eu un problème d’initialisation cela peux résoudre ce problème. Mais sinon vous ne devriez pas à avoir a utiliser cette combo.

### Derniers détails

L’écran de base indique les coordonées RA/DEC actuelles.
Il indique aussi la vitesse (Spd) de déplacement que vous savez maintenant changer. Il indique la vitesse de suivit. Ici Sidéral. Que vous savez aussi changer !
Le dessin a coté de la vitesse indique si le telescope est a l’est ou a l’ouest de la monture. Notez que vous retrouverez ce dessin dans les selections d’objets type Messier, Ngc… Si il est aiché, cela indique que l’objet en question est de l’autre coté du méridien par raport a la position actuelle du télescope.
Pour finir si la vitesse est « barrée », cela indique que la monture n’est pas allimentée en 12V, mais seulement via la prise USB, ce qui n’est pas suisant pour faire bouger les moteurs !

## Utilisation assistée par ordinateur

C’est une fois connectée à un ordinateur que le système montre toute sa puissance.

### Connection filaire, driver Ascom

Il y a 2 connections possibles, la connexion filaire (conseillée car plus stable), MAIS qui est de temps en temps problématique.
En eet la connexion USB est souvent mal faite sur les ordinateurs. Et quand on alimente la monture en 12V, il se peut que le 0V (masse) de l’alimentation ne soit pas équivalent au 0V de l’USB. Mais sur la raquette, les 2 0V sont les mêmes. Sur certains ordinateurs cela peut poser problème. De temps en temps l’ordre de connexion change les choses. Soit il faut d’abord connecter le 12V, puis l’USB, soit dans le sens inverse. Ecoutez le PC et les « bit bip » de connexion USB pour avoir une bonne idée de ce qui se passe.

### Installation Ascom

Il va vous falloir installer le logiciel, Vous allez devoir installer le système Ascom, puis copier les 4 fichiers ASCOM.BrebissonV1.exe, issposdll.dll iss.wav et power.wav dans le répertoire C:\Program Files (x86)\Common Files\ASCOM Puis, ouvrerez une invite ligne de commande (touche windows +R, tapez cmd, enter), aller dans le répertoire ascom en tapant « cd " C:\Program Files (x86)\Common Files\ASCOM" » enter
Puis taper : « ASCOM.BrebissonV1 /register »
Cela à pour eet d’enregistrer ce programme dans le système Ascom.

Lancer ASCOM.BrebissonV1.exe et vous verrez cette interface.

### Connection « com »

La première chose à faire vas être de « connecter » le programme a votre raquette que vous aurez branché sur votre ordinateur via le port USB. Cela se fait via ce que l’on appelle un port « com ».
Dans tous les cas il va vous falloir « trouver » quel est le port COM utilisé par votre raquette.
Si le logiciel de contrôle à été lancé APRES que vous ayez connecté la raquette au PC, il va vous falloir appuyer sur le bouton « scan coms » pour recréer la liste des ports com qui est aiché à gauche du dit bouton. Mon conseil est de regarder la liste, de scanner les coms, et de re-regarder la liste. Le « nouveau » com est celui de votre raquette !
Si le logiciel à été lancé avant… vous pouvez essayer les divers coms, ou alors déconnecter votre raquette, rescanner la liste et procéder comme indiqué ci-dessus. Puis appuyer sur le bouton « connect » qui deviens alors « disconnect » pour que le programme commence à parler à la raquette…

### La fenêtre principale

S’aiche la position actuelle du système. Notons que dans les premières versions la raquette vas redémarrer et perdre sa position ! Si le télescope était en position « nord », le PC qui connais l’heure locale vas, en utilisant les données de positions indiquées dans le setup calculer la position en AD automatiquement. Si votre télescope est parfaitement aligné en position nord, vous êtes donc a peu près synchronisé.
La partie « mount » indique la position actuelle. La touche Copy vas la copier dans les 2 boites d’édition dessous qui permettent de faire un goto ou sync.
Les touches goto et sync permettent de faire un goto ou sync à la position indiquée dans les 2 boites de texte sous la position actuelle.
Le bouton stop arête tout mouvement du télescope.
« Mount East »/ « Mount West » correspond à l’appui sur les touches Esc puis Sync de la raquette. Cela change la dirrection de l’axe delta. Si il y a eu un problème d’initialisation cela peux résoudre ce problème.
Le bouton flip enable/flip disable permet d’arrêter le retournement au méridien. Cela fait que le télescope peu se retrouver la tête en bas ! A utiliser quand vous savez ce que vous faites !

Notons l’indication « flip in : 6 :23 » qui indique qu’il reste 6h23 minutes avant un retournement au méridien (si le télescope reste pointé sur le même objet).

Dessous, vous avez une drop box qui indique la vitesse de déplacement sidéral. Vers la droite, 4 touches permettent de bouger le télescope à la vitesse indiquer juste au-dessus.

En bas de la zone, Park/unPark permet de « parker » la monture, c’est-à-dire de la remettre en position « nord » et d’arrêter le mouvement sidéral. Unpark se contente de relancer le mouvement sidéral.
Flip force un retournement au méridien. A utiliser quand le télescope est en bout de course pour forcer les choses a un moment opportun pour vous.
isNorth vas « assumer » que le télescope pointe au nord et forcer les coordonnées correctement.
Et finalement les boutons +90° et -90° permettent de forcer la monture a faire 90° en plus ou moins en RA. C’est très utile lors de la mise en station avec sharpcap ou il faut faire décrire 90° au télescope !

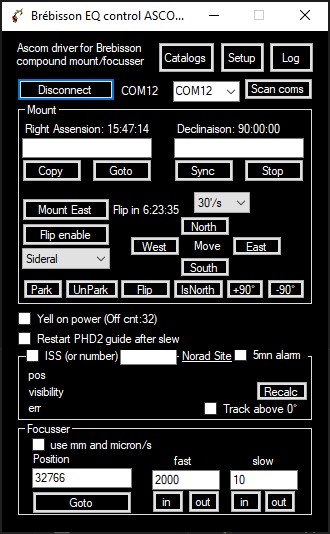
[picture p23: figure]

Le checkmark « Yell on power” vas faire que le programme va jouer le fichier son
« power.wav » si il détecte une perte de 12V. Très utilise si on est en nomade sur batteries.
Le checkmark « Restart PHD2 guide after slew” vas faire que PHD2, si il est actif vas être relancé en mode guidage après une opération de goto. Comme PHD2 s’arrête lorsqu’il détecté un mouvement de télescope, cela permet de le relancer automatiquement si votre logiciel de prise de vue ne le fait pas.

### La section ISS !

Sélectionner ISS et le système va se connecter au site du Norad (oui, comme dans WarGames !) et récupérer les données orbitales de l’ISS (ou de tout autre satellite dont vous indiquerez le numéro dans la zone d’édition a côté de ISS. Cliquer sur « Norad site » pour rendre visite au site du Norad et trouver les infos sur les satellites. Sélectionner 5mn alam pour avoir ma jolie voix vous indiquer que l’ISS vas arriver 5mn avant qu’elle ne dépasse l’horizon.
Vous allez ensuite voir la position de l’ISS en ra/de cet az/alt, suivit d’une indication
« NotVisible » (pas visible) et le temps a attendre avant qu’elle ne passe au-dessus de l’horizon. Vous aurez aussi l’indication de la « hauteur » du transit (ici 19°, pas très haut), de la durée (9mn) et de la vitesse max (ici 0.8° / s).
Notons que si le système ne peut pas se connecter au Norad car la ligne est occupée par Matthew Broderick, il utilisera les dernières infos connues.
Sélectionner « Track above 0° » et le système vas suivre l’ISS des qu’elle sera au-dessus de l’horizon !
Pour que cela marche bien il faux mieux préparer le télescope quelques minutes avant (d’où l’alarme). Placez le environ 20° au-dessus de l’horizon dans la zone ou l’ISS vas arriver, faite une synchronisation sur la position pour être le plus précis possible (si vous le faites trop bas la réfraction atmosphérique peux troubler les choses). Puis descendre le télescope proche de l’horizon et attendre.

Quand l’ISS deviens visible, et que vous êtes en mode « track » vous aurez cet écran-là :

La partie importante est la zone d’édition indiquant « Press up/down/right/left to correct. » cliquer dedans et utiliser les touches haut/bas/droite/gauche de votre ordinateur pour envoyer des corrections supplémentaires au système. Cela vous permet de corriger manuellement toute erreur de position.
Le système va tracker l’ISS (ou le satellite) tant qu’il le peut.
Notons que si le satellite va trop vite, il n’y arrivera pas (mais il essayera), plus le satellite sera près du zénith plus il ira vite. LA monture arrivera probablement au méridien a un moment et voudra se retourner ! Si elle y arrive assez vite, elle continuera à tracker… La correction en arc seconde sera indiquée pour info.
Quand vous de-cliquez le bouton track, un log des positions sera ajouté sur le desktop.

### La section Focusser

Ici vous pouvez utiliser l’option focus du contrôleur. En eet ce système est capable, en plus du télescope de contrôler le focus de votre optique si elle est motorisée.
Le checkmark « Use mm and micron” indique si vous voulez travailler en pas, ou en distances réelles.
La position indique la position actuelle en pas (toujours positive) ou en mm (positive ou négative).
Les boutons in/out fast et slow permettent de faire bouger le focusser a une vitesse donnée en pas ou microns par secondes.

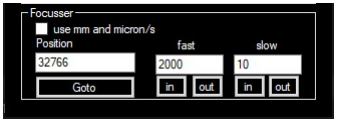
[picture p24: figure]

## La section setup

Cliquer sur le bouton « Setup » pour entrer dans la section de configuration.
Vous y trouverez les informations sur l’observatoire. Ces infos sont principalement informative et seront utilisé par le logiciel de capture d’image pour régler le plate solve et pour tagger vos photos. La longitude sera utilisée par ce logiciel pour calculer l’heure sidérale (important).

Vous allez ensuite trouver 3 zone similaire des configurations des moteurs pas à pas. Dans tous les cas il va falloir indiquer le nombre de pas maximum, qui correspondront a un tour complet dans le cas des moteurs RA/DEC et de l’amplitude max pour le focusser (notons que celui-ci est limité a 65535 pas).
Il faudra indiquer le nombre de pas max par seconde (la vitesse max en gros) et le temps d’accélération pour arriver a cette vitesse max en ms.
Il vous est aussi possible d’indiquer un baklash. C’est-à-dire un nombre de pas ou d’arc secondes a rajouter sur tout mouvement quant on inverse la direction de mouvement. Cela permet de gérer les jeux mécaniques.
Vous pouvez aussi indiquer le ‘sens’ du moteur via la ckechbox ‘invert’.
Dans le cas du focus, si vous indiquer la taille d’un pas en microns, cela permettra aux meilleurs soft astro (genre Prism) de gérer les choses en mm ce qui peut être très pratique dans certains cas (par exemple los de l’ajout d’un filtre).

Dans le cas du mouvement en RA, vous pouvez indiquer l’amplitude en °. 180° signifie que l’axe RA ne dépassera jamais l’horizontale. Dans la réalité, il est généralement utilisé de permettre un mouvement de 30 minutes à 1h de plus de chaque côté de l’horizontale. 30 minutes de RA étant 7.5°, ajoutons 2*7.5=15° a 180 pour 195°. Notons la présence d’une aide au calcul de pas en bas. C’est juste une suite de multiplication et de divisions qui vous évite d’avoir à sortir la calculatrice !
Les drivers de type DRV2209 qui équipent mes dernières montures sont en 256 micros pas. La plupart de moteurs pas à pas sont en 200 pas par tours, les EQ3 ont une réduction mécanique de 130 :1 en RA et 65 :1 en dec. Les EQ5 144 :1 sur les 2 axes. Si vous avez des poulies, il va falloir les rajouter via les ‘gear’. Pour finir il y a une division qui permet de calculer la vitesse en pas/s selon ce que vous désirez, et ce que votre monture supporte.
La section guiding permet de configurer le guidage. Donnez la vitesse de guidate en arc" par seconde de contrôle. J’ai ajouté des options pour moduler le contrôle du logiciel de guidage ‘agresivity, qui se multiple a la consigne), pier invert qui inverse la consigne suivant le coté du télescope, invert qui inverse la consigne tout le temps et stop qui bloque le guidage sur un axe. Mais normalement il n’uy a pas lieux d’utiliser ces choses que j’ai ajouté principalement pour faire mes tests..
La section « Time base » est une analyse de la diérence entre la théorie et la pratique. Il va analyser la manière dont la raquette et le PC perçoivent le temps et vas permettre (en assumant que le PC est correct) de calculer une correction (en cliquant sur le bouton Auto). Laisser tourner le système au moins 5 minutes avant d’utiliser cette fonction !

On y voit la base de temps PC, la base de temps HW et la diérence. On y voit aussi le nombre de pas par seconde en sidéral « envoyés » par le HW et l’erreur.
Les arduinos ont généralement un drift non négligeable. Mais les ESP32 sont très bon et n’ont pas besoin de correction.
Les ESP32 ont un réglage de wifi.
Vous pouvez sélectionner le mode AccessPoint (la raquette est un server wifi), ou
« client » ou il se connecte à votre réseau wifi. Indiquez le nom du réseau et le mot de passe. L’adresse IP vous sera indique ici aussi.
Pour finir le bouton « save in HW » vas « écrire » toutes les données dans la raquette (et faire un reboot). Reload from HW permet de recharger les données qui sont dans la raquette si vous avez changé un truc et que vous voulez revenir à la vraie valeur.
Save conf et load conf permettent de sauvegarder une configuration sur PC.

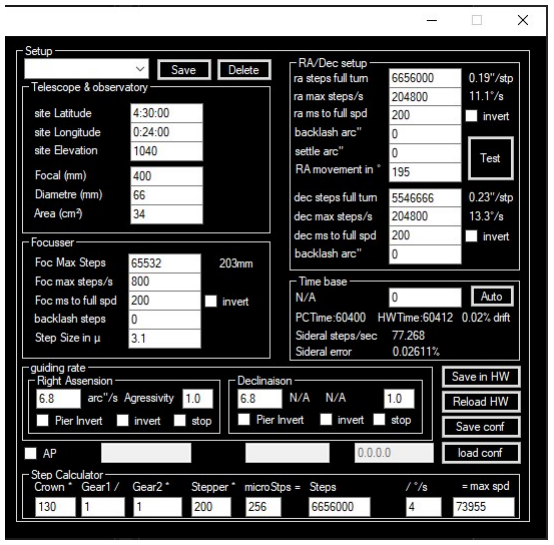
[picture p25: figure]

## La fenêtre Catalogs

Bone encore une chose à moitié faite….
Cliquer sur Messier, Cadwell, Ngs, Stars et planètes pour aicher à droite la liste en question. Sélectionner un des objets et cliquer sur GoTo ou Sync pour faire un Goto ou un Sync. C’est une version ordinateur des menus équivalents de la raquette.

L’écran montre la position du télescope sur la voute céleste. Vous pouvez bouger la vue avec la sourie, et si vous sélectionnez un objet dans cet ecran et qu’il apparait en bas de l’écran, les touches goto et sync permettent les actions habituelles.
Le bouton « OnScope » recentre la vue sur le télescope.

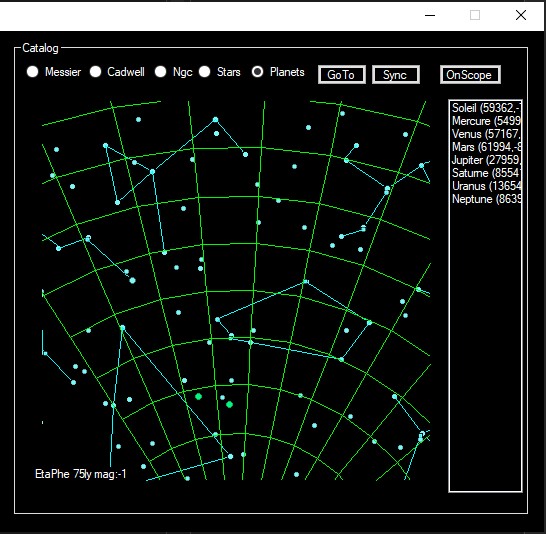
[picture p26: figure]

## La fenêtre « log »

Cliquer sur Log pour voir la fenêtre le log. Vous y trouverez principalement un log de tout ce qui c’est passé au sein de la monture. Les check box « show system », « show
ascom »… etc permettent d’ignorer certains évènement qui ne vous intéressent pas.

### 2 lignes de texte montrent les communications entre la monture et le PC en hexa et en

« clair » et permettent de faire un freeze des choses pour étudier les choses en détail (principalement pour faire du débug).
Les 4 touches « pulse guide » permettent d’envoyer des pulsations de guidage. C’est utile pour tester le backlash de la monture de jour sur une cible fixe.
La section moteur indique la position des moteurs en pas et en % de mouvement.

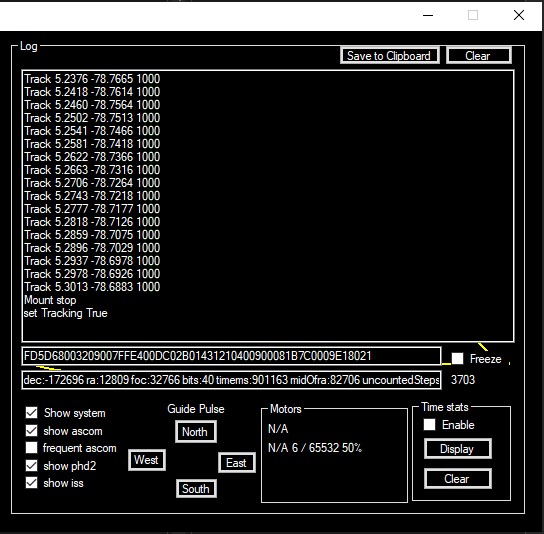
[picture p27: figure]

## Liaison avec Stelarium

Comme ce programme est un driver Ascom il est utilisable pour connecter votre télescope a tout logiciel gérant Ascom tel que Prism, SharpCap, Stellarium ou PHD2. Je me contenterais d’expliquer l’utilisation dans Stellarium qui est assez complexe tout en étant super utile pour un débutant.
Premièrement, lancer le plugin contrôle télescope. F2 ou configuration window/ Plugins, telescope control (ou controle de telescope), sélectionner « lancer au démarrage). Redémarer stellarium.

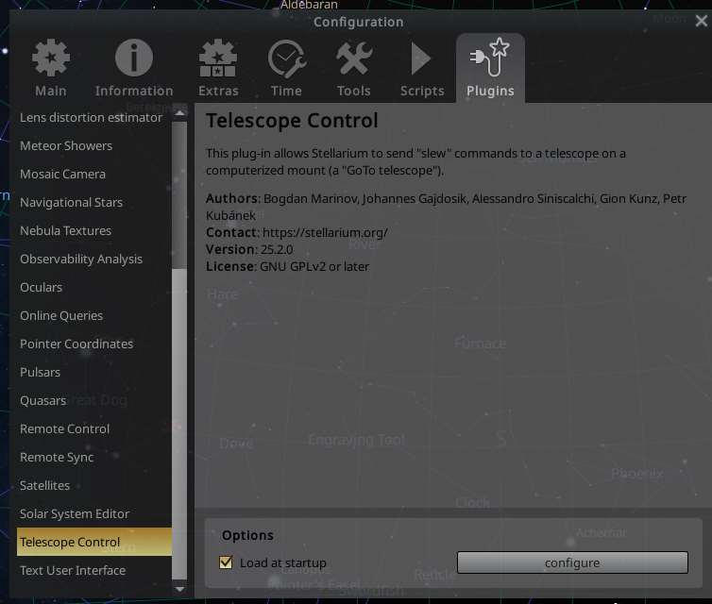
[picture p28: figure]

Cliquer sur ‘contrôle télescope’ qui est maintenant dans la barre d’actoin en bas. « configure telescope » Add new telescope , Ascom, choose ascom telescope, et séléctionner Ascom telecope driver pour BrebissonV1.

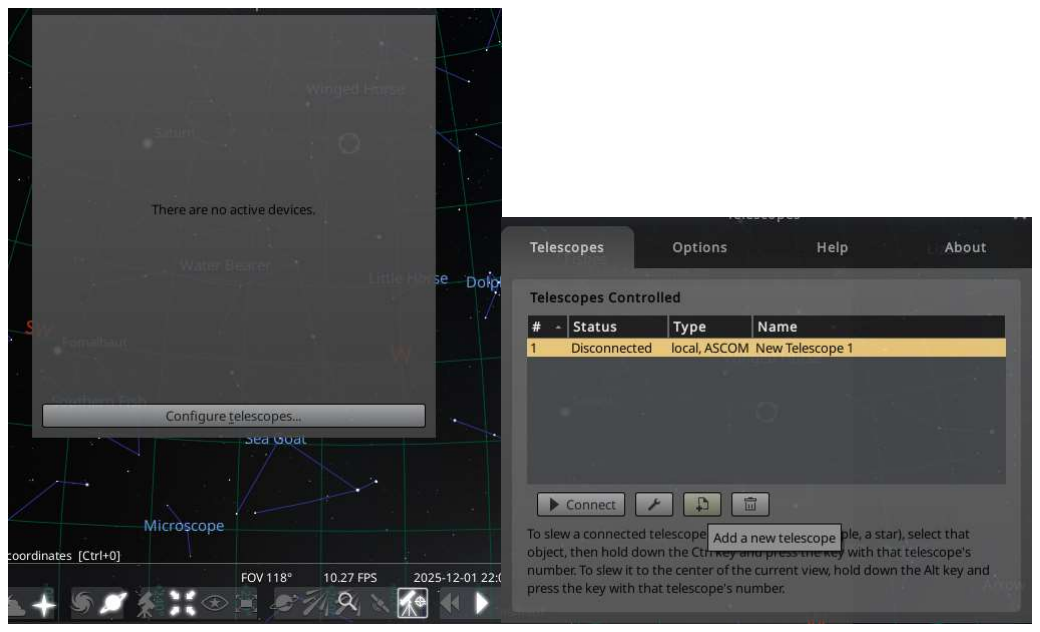
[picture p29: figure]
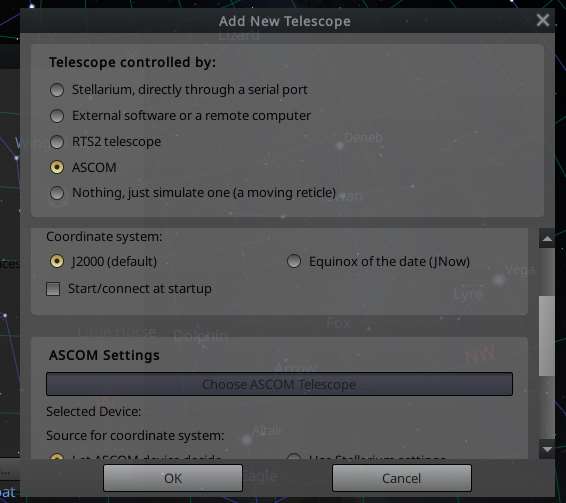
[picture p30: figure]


Connecter le telescope et vous allez voir l’UI suivante : Stellarium montre ou pointe le télescope avec le réticule. Et la boite de dialogue permet de pointer le télescope. Pour se faire, sélectionner un objet dans stellarium en cliquant dessus, puis cliquer sur
« current objetct » dans la boite de contrôle du télescope, puis « Slew » pour faire un Goto. Sync permet de synchroniser. L’interface est un peu bizarre mais marche.


## Liaison avec SharpCap

Si votre télescope a une caméra vous pouvez utiliser Sharpcap pour synchroniser.

Dans Fichier, SharpCap settings, Hardware, section « mount », séléctionner “Ascom Telescope driver for BrebissonV1”. Note, vous pouvez aussi connecter le focusser!


Conencter la camera puis assurez vous que la monture est connéctée :

Prenez une photo des étoiles (pas de moi), et utiliser le menu « tools, plate solve and resync » pour que sharpcap fasse un plate solving et synchronize la monture.

## Liaison Alpaca (esp32 seulement)

Alpaca est le nouveau système de connexion Ascom qui utilise le réseau.
Pour utiliser Alpaca, votre raquette devra être sur le réseau de votre ordinateur. Soit via une borne wifi « générale », ou connecté a votre PC, ou en mode « serveur » ou c’est la raquette qui sert de borne wifi.
Dans les 2 cas la configuration se fait via le programme driver Ascom normal via la ligne ou on spécifie le réseau wifi. En mode AP (Access Point), la raquette se comporte comme une borne wifi et vous devrez y connecter votre ordinateur. Dans l’autre cas c’est la raquette qui essayera de se connecter au réseau. Utiliser le même nom dans les

### 2 cas simplifie bien les choses !

Sur la raquette l’interface suivant apparaitra après l’interface focusser. Elle indique l’adresse IP de la raquette (ici 0.0.0.0 en mode test), et le nom du réseau (ici blanc car je suis en mode test). Vous pouvez utiliser les touches haut/bas pour passer du mode AP au mode station (attention, il vas y avoir un reboot du système).

Normalement sharpcap et autres programmes Ascom pourront alors se connecter a la raquette.
Mais vous pouvez aussi vous connecter via un browser internet a http://x.x.x.x/setup ou les x sont remplacé par l’adresse ip de la raquette.
Cela vous donnera access aux fonctions de base du système.




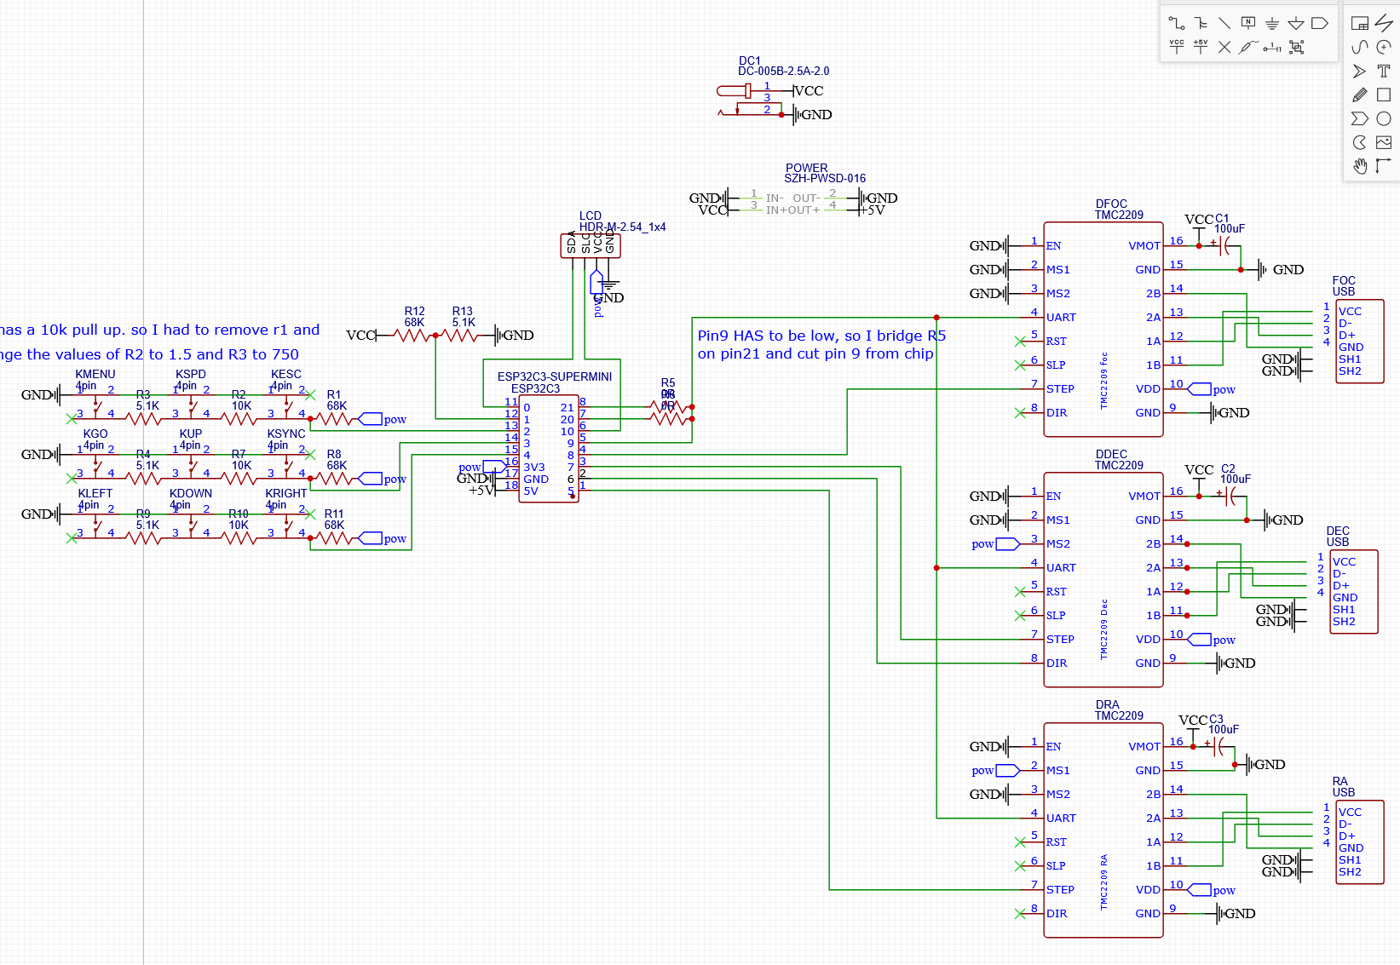
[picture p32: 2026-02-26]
Hardware_and_mechanicals/pcb1.png

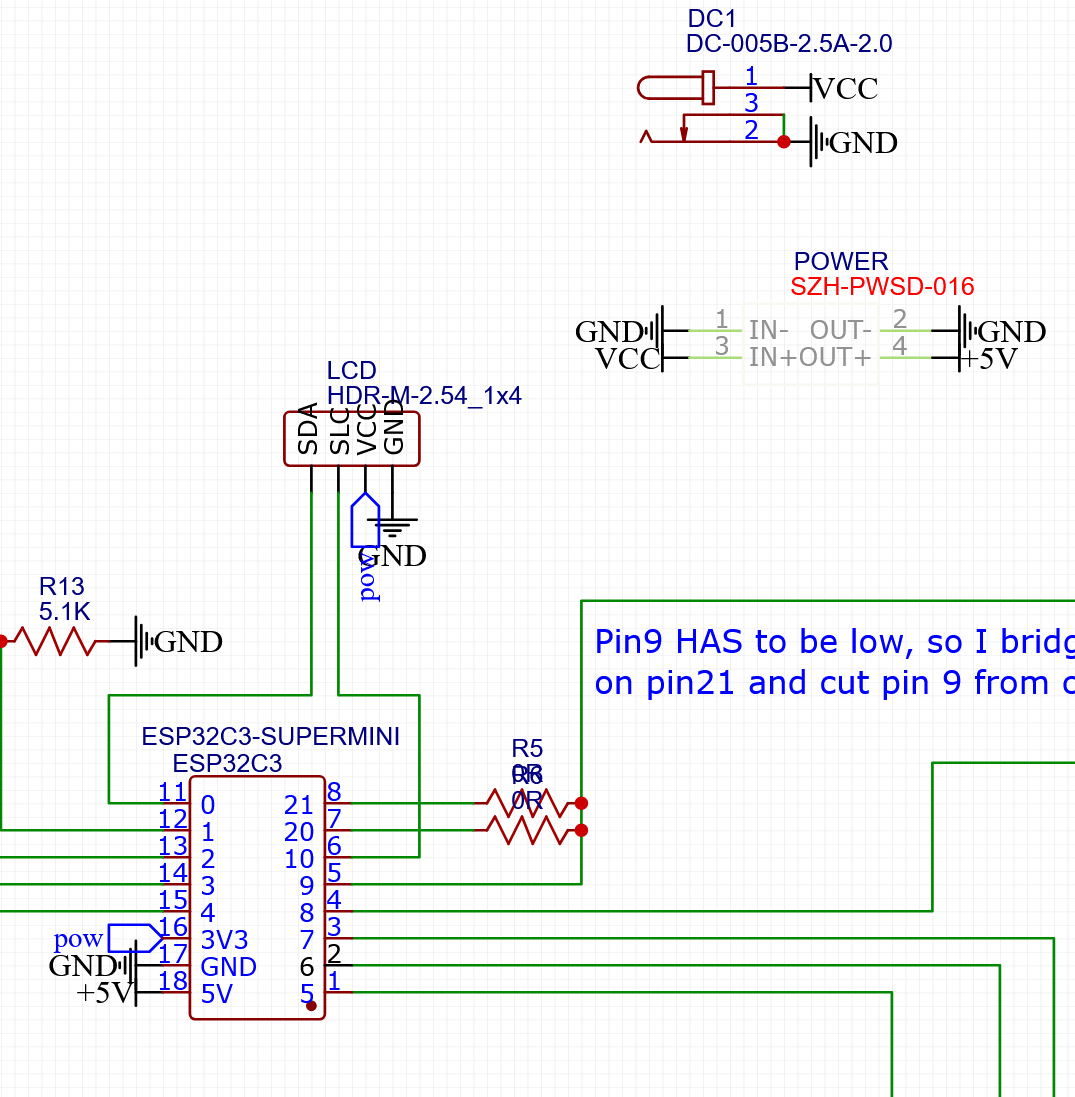
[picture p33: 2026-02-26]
Hardware_and_mechanicals/pcb2.png

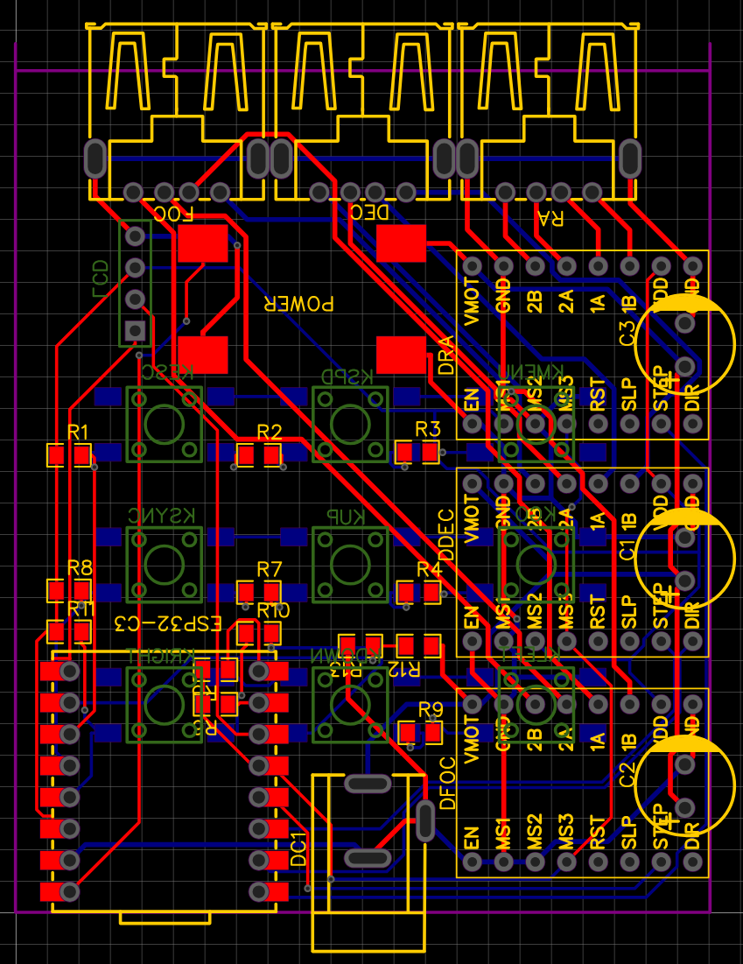
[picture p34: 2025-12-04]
Hardware_and_mechanicals/PCB.png

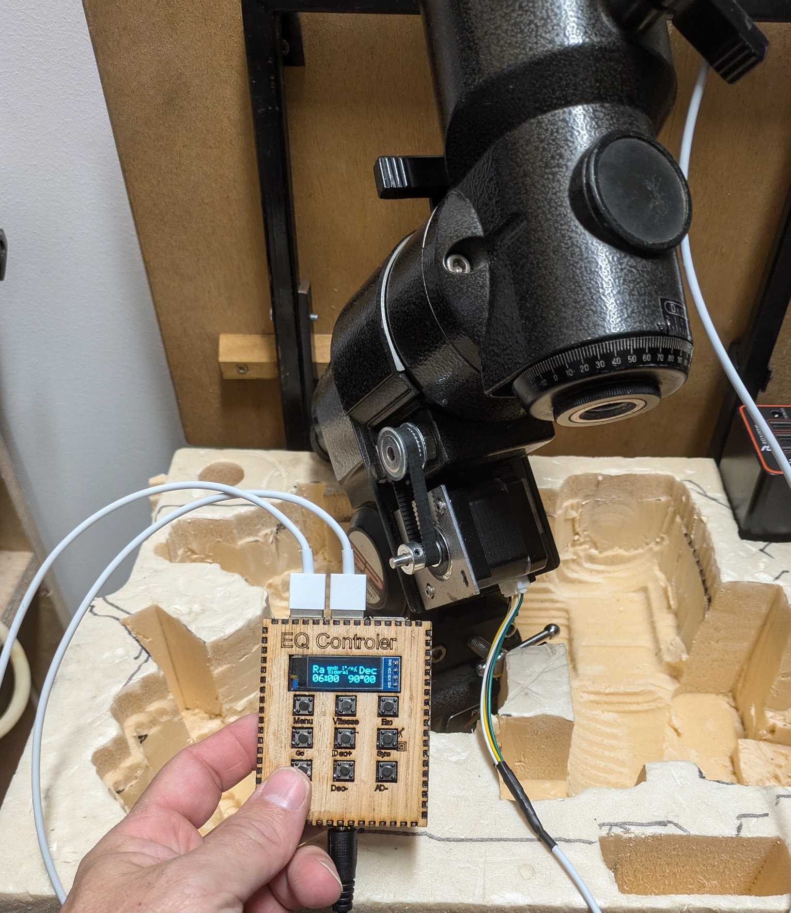
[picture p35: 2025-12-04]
Raquette.jpg

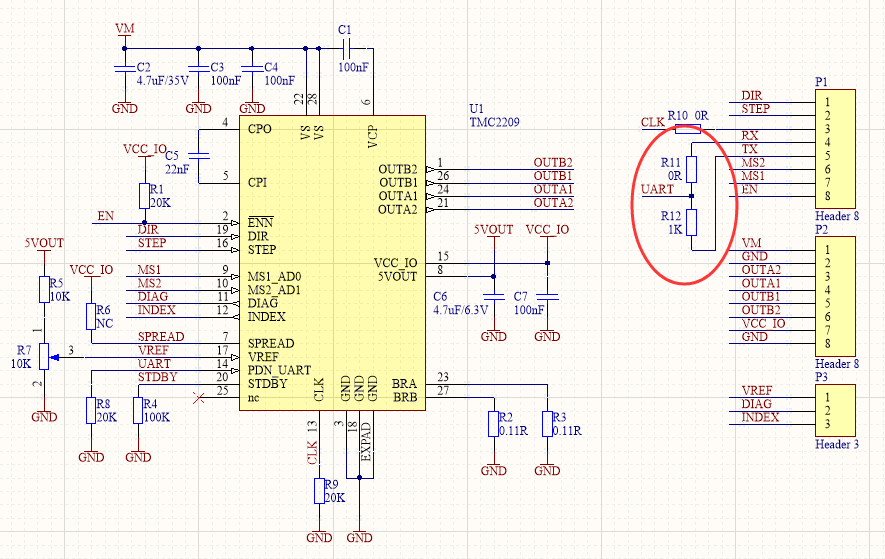
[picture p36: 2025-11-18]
Firmware/tmc2209 shield.png

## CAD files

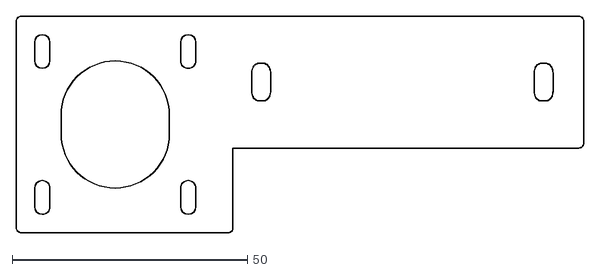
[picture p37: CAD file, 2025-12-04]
Hardware_and_mechanicals/eq5_ra.dxf
120.5 x 46.0

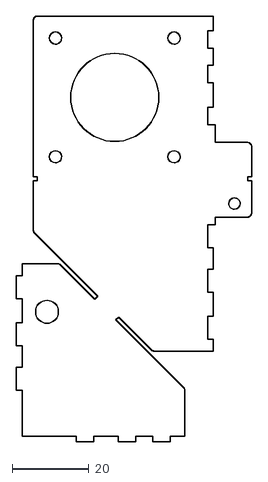
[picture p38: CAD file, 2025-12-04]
Hardware_and_mechanicals/eq3_5 dec.dxf
61.5 x 111.2

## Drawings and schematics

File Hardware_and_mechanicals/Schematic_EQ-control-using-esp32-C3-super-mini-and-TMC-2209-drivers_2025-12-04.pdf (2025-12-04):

## Pin9 HAS to be low, so I bridge R5 Pin2 has a 10k pull up. so I had to remove r1 and

change the values of R2 to 1.5 and R3 to 750 | on pin21 and cut pin 9 from chip

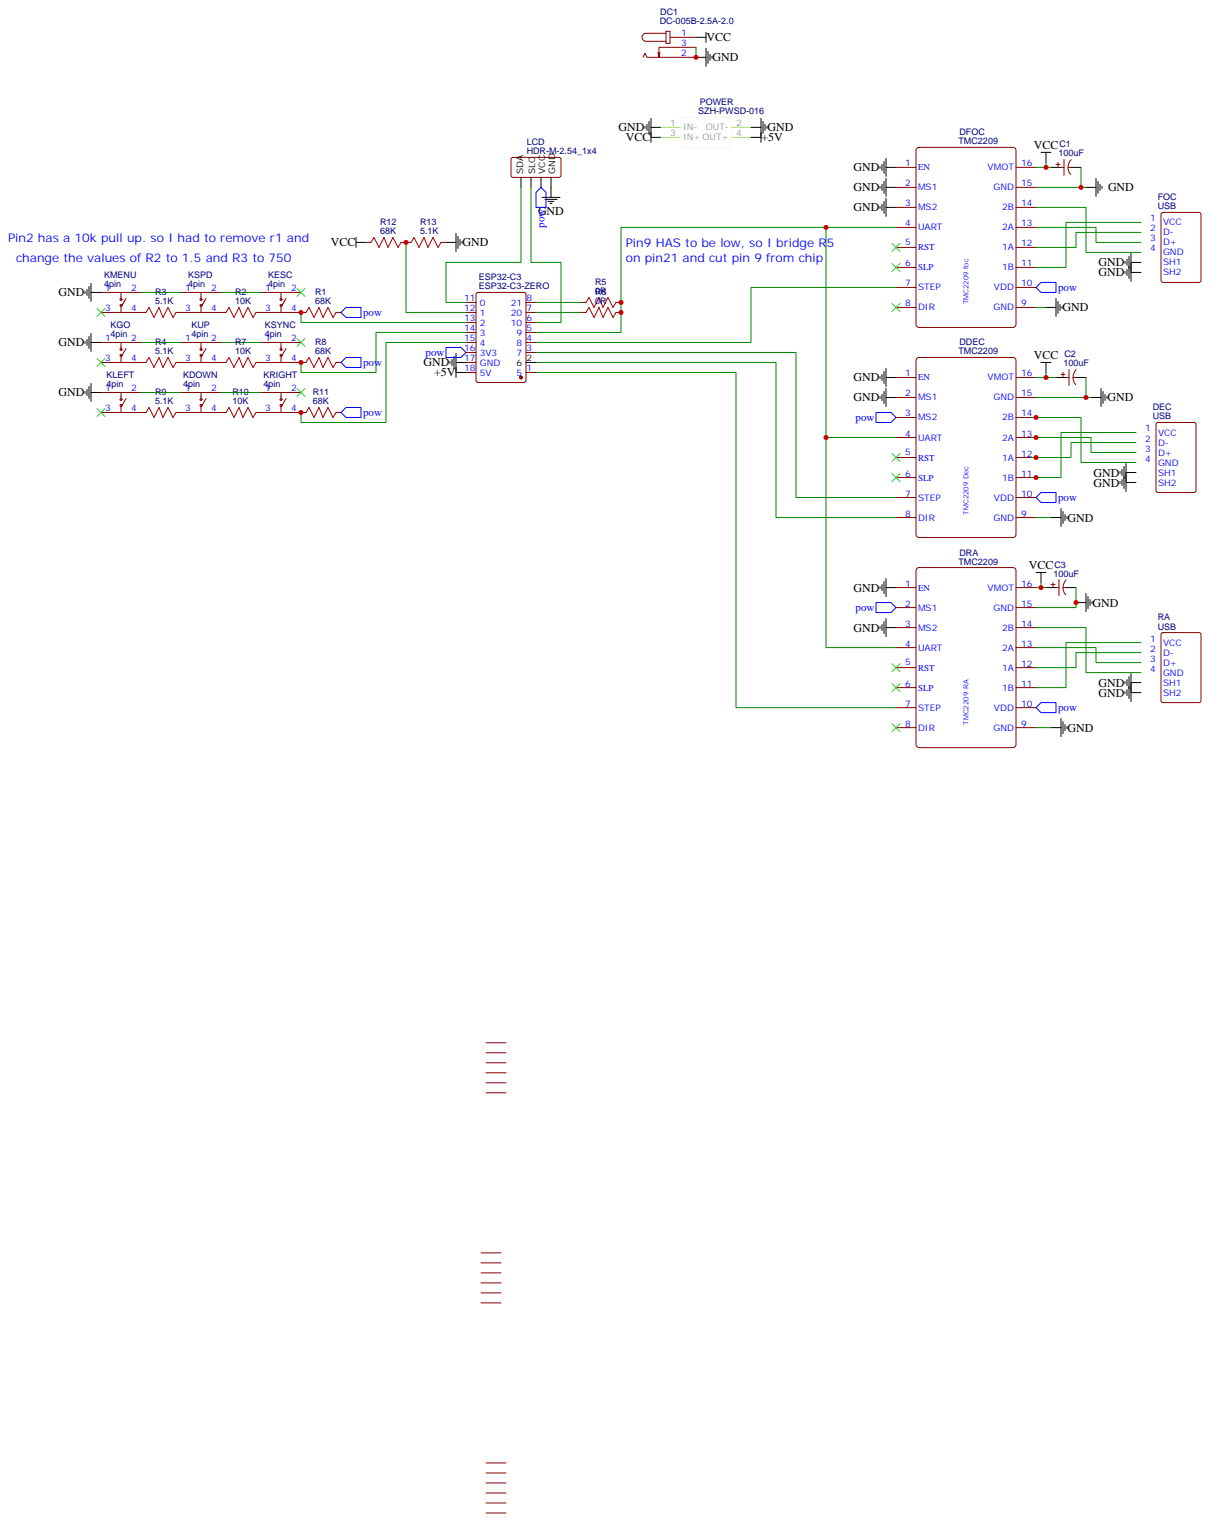
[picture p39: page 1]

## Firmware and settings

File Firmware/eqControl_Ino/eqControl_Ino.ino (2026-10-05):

// This code is copyright Cyrille de Brébisson
// Contact me if you want to use all or part of it.
// Most likely I will say yes unless it is for commercial use at which point we can discuss


#define TMC // in arduino (__AVR__) nano mode, you can select the TMC or non TMC driver... in esp, it is ALWAYS tmc...
#define HASADC // in __AVR__ mode, IF TMC, this is used to monitor the power supply and handle motor configuration. Some older versions had TMC but no ADC...
               // in ESP mode, the first PCB did not use the ADC. PCB2 uses the ADC for keyboard + power supply. This includes my main eq3 control board!
//#define HASGPS // in ESP mode, you can have a GPS module used to get the LST...
//#define WEIRED_KBD // I had some early ARV boards with a slightly differnet keyboard. Uncomment for those
#define RED_BOARD // define for esp32 RED boards...
#ifdef RED_BOARD // red board has all options...
    #define TMC
    #define HASADC
    #define HASGPS // in ESP mode, you can have a GPS module used to get the LST...
    #define HASBNO
#endif
#ifdef HARMONIC_MAIN
    #define TMC
    #undef HASADC
    #undef HASGPS
    #undef HASBNO
#endif

/********************************************
* 
* Equatorial mount controler with keyboard/screen based UI and Ascom drivers
* With optional focusser control
* 
* tracks at sideral speed (can not be turned off)
* Can be controled through the serial port associated with an ASCOM driver
* 
* provides a full UI on the device using a 9 key keyboard and a 32*128 screen (No move to larger screen, this works well)
* This UI allows basic movements (including speed selection and spiral),
* synchronization and goto on over 700 NGC, Messiers, Cadwell, 170 named stars and the planets!
* The UI also allows configuration of the stepper motors.
* Finally, it allows start/stop of sideral movement, enable/disable of meridian flip and changing side of pier
* 
* The same features are available through the Ascom driver.
* The Ascom driver also allows tuning of time drift.
* 

//////////////////////////////////////////////////////////////////////////////
*
*                           User manual
*
* Handheld manual
*
* Connect the RA and Dec motors to the device. Optionally connect the focus. DO NOT connect/disconnect when powered! Can burn the HW
* Connect 9V to 15V to the bottom barrel connector. If not powered then the speed display will be crossed off and no movements are possible
*
* Display indicates current RA and DEC spot. the speed and a telescope that indicate side of pier.
* The screen will turn off after 10s.
*
* RA/DEC keys will move the telescope at the given speed in the appropriate direction. RA movement is limited to 180° (unless otherwize configured)
* The speed key allows to change the speed of movement (from 1 arc minute/s to 4°s)
* Sync/Spiral key, if held, will move the telescope in a spiral fashion to find objects. The size of the spiral will depend on speed (small speed=small spiral)
*
* The menu key circles through the menu. The Esc key returns to the original screen
*
* Messier, NGC, Cadwel an stars menu: Use the RA/DEC keys to select an object (RA moves 1 object at a time, DEC 10 objects at a time)
* press SYNC or GO to sync the scope on this object or go to the object.
* Note: When selecting an object the "telescope" icon will be displayed next to the object name if a move there will result in a meridian flip.
*
* At startup, make sure that the telescope is pointing north (polar align). Then use the keys to move to a known object and 'sync'.
* This will calibrate the scope. Althrough you can move Dec manually, do NOT move RA manually as it is important for the
* system to know where it is in RA to limit the movements to +/-90° around the "vertical".
* Once synced, you can then select an object and "Go" to it!
*
* For planets, you have to enter the current date. Use the RA buttons to cycle through the day, month, year and selected object and Dec buttons
* to select the actual value. Go and Sync will work as for the Messier and other objects...
*
* About meridian flip
* Enable/disable meridian flip by pressing and holding the Esc button, and then pressing the DecUp key, then releasing the Esc key. You will see a small _ under the telescope icon
* If the dec is going the wrong way for you (dec has not flipped), press and hold Esc, press Sync, release Esc. You will see the telesocpe icon switch. The dec direction has been inverted
*
* Focusser
* In the focusser menu, use the RA and Dec buttons as fast and slow movement of the focusser. The position is indicated in mm assuming that you have configured the step size in Ascom driver
*
* On controler stepper conifg menu
* You can do basic configuration of the stepper on the handheld. But this is not advised as the Ascom interface does it much better
* Use the go/sync buttons to select an item to change and then the RA/DEC buttons to change it (RA=slow speed, DEC= fast speed).
* Press Escape to cancel and speed to validate and save the settings...
*
*
* ASCOM
* The true power of the system can only be realised when connected to a PC!
* Install the Ascom system, install the eq3 driver (copy in C:\Program Files (x86)\Common Files\ASCOM and then run it from the command line with the /register parameter)
* Start the .exe select a com port and click on connect.
* Click on setup. You can change all the parameters there! Validate and you should be good to go
* Special note about the "time compensation". Time on the arduino is not very accurate
* So the device will send its time to the PC on a regular basis. After around 1minute the PC will be able to start comparing
* the time provided by the arduino with its refence clock and compute the error. My advise is to wait at least 10 minutes
* to give time to the CPU to get to temperature (yes, it is temperature sensitive) and then press the "auto" button
* next to time comp. This will compute the time compensation. Then press on update HW to send the data to the HW.
* Accurate time is critical for good tracking.








* Handles side of peir, and meridian flip. Althrough the meridial flip is badly implemented and is not working well...
* Meridian flip is nessecary if we do not want the scope to bang on the mount.
* It is possible, because they are 2 ways, in spherical coordinates, to indicate one direction
* This means that if scope is right of pier, the dec motor needs to work in one direction, and if left, in the other direction...
* This also means that the scope needs to know the physical position of the RA axis (or at least the 90° position, weight at the bottom)...
* Then it can know how to handle the dec axis...
* To do this, it is ASSUMED that the scope gets started weight down. This allows the scope to never move the RA axis more than 90 deg
* right or left from this position. This is the physical mark.
* It then applies an offset to know the RA hourly value.
* 
* As earth rotate, the logical coordinates will slowly shift with adjustments made to the ra logical min/max to match real position.
* But the physical position will also be incremented so that the scope knows its physical position too... until the max pos...
* 
* When syncing, only the logical coordinates will be changed to sync the scope.
*
* Dec however is different...
* Dec values are from -90 to 90 on both sides of the rotation. i.e: top is 90 and you can get to -90 going right or left
* (think about being on the north pole and trying to get to the south. You can do it on the greenwitch meridian or the 180deg meridian)
* both will get you to -90 (south)...
* Direction of travel should be one way if ra is past meridian, and the other way if ra is before meridian.
* if ra is at meridian, it does not mater...
* 
* 
* Current state:
*   Understand/fix meridian flip at startup, direction at startup and how to "virtual flip" when moving RA...
*   Need to add new output 12V controler
*********************************************/

#include <stdint.h>
static uint16_t const keyMenu=  1<<0;
static uint16_t const keyGo=    1<<1;
static uint16_t const keyLeft=  1<<2;
static uint16_t const keySpd=   1<<3;
static uint16_t const keyUp=    1<<4;
static uint16_t const keyDown=  1<<5;
static uint16_t const keyEsc=   1<<6;
static uint16_t const keySync=  1<<7;
static uint16_t const keyRight= 1<<8;



#if defined(__AVR__)
// Motors are and serial receive/send is IRQ based...
// display takes 5ms
// handleing next for both motors at full speed is around 75µs. limiting to 10K steps per second to keep room for the rest of the code!
// dealing with serial reply takes around 150µs



// Arduino Pin Layout
// pins 0-7 are on PORTD
// pins 8-13 are PB0-5. 13 is LED.
// pins 14-19 (A0-5) are PC0-5
// A6/A7 are analog only pins...
// pins 0/1: RX/TX
// pins 2-7: stepper control
// pins 8-10: steper serial pins
// pins 11,12,14-17: kbd
// pin 13: LED
// pins 18 (SDA),19 (SCL): I2c for the screen

// Stepper control pins. Have to be using 2 to 7...
static const int8_t raDirPin    = 2;  // this is port D
static const int8_t decDirPin   = 3; 
static const int8_t focDirPin   = 4; 
static const int8_t raStepPin   = 5; 
static const int8_t decStepPin  = 6;
static const int8_t focStepPin  = 7; 
static const int8_t motorSerialRa = 8; // This is port B
static const int8_t motorSerialDec = 9;
static const int8_t motorSerialFocus = 10;
static const int8_t raUartAddr= 3;  // on arduino they are all at 3 but uses 3 separate pins...
static const int8_t decUartAddr= 3; 
static const int8_t focUartAddr= 3; 
// LCD control. This is for information only as the I2C hardware is hard wired on them anyway...
static const int8_t displayClk  = 18; // A4
static const int8_t displayIO   = 19; // A5

static int const maxPulsesPerSecond= 10000;
static void inline my_delay_us(uint16_t us)
{ // at 16mhz, we need 16cycles / us
    __asm__ __volatile__ (
        "1: sbiw %0,1" "\n\t" // 2 cycles
        "brne 1b" : "=w" (us) : "0" (us) // 2 cycles
    );
}
static void udelay(uint16_t us) { my_delay_us(us*4); }

__attribute__((always_inline)) inline void DoNotOptimize(const uint8_t &value) { asm volatile("" : "+m"(const_cast<uint8_t &>(value))); } // This is a guard around step toggle to make sure that the time requirement is met.

static void inline portSetup() 
{ 
    #ifdef TMC    
        DDRD|= 0b11111100; PORTD= 0b00000000; // Set all motor pins to out and the direction pins to low. pins 0/1 are used by serial and not an issue...
        DDRB= 0b111111; PORTB= 0b011111;    // Set B port pins (motor serial + kbd rows0-1 + led) to out and high, except for portB5 which is pin 13=LED
        // Here we also define the code to use to toggle step pins depending on the motor... in TMC, pin change means step...
        #define STEP1(pin) PORTDTOGGLE(pin)
        #define STEP2(pin)
    #else
        DDRD|= 0b11111100; PORTD= 0b00011100; // Set all motor pins to out and the direction pins to 1. pins 0/1 are used by serial and not an issue...
        DDRB= 0b111111; PORTB= 0b011100;    // Set B port pins (motor enable + kbd rows0-1 + led) to out and high, except for RA and dec enable and portB5 which is pin 13=LED
        // Here we also define the code to use to toggle step pins depending on the motor... in DRV, pin up then down with at least 2us interval means step...
        #define STEP1(pin) PORTDSET(pin); DoNotOptimize(pin)
        #define STEP2(pin) DoNotOptimize(pin); PORTDCLEAR(pin);
    #endif
    DDRC= 0b001000; PORTC= 0b001111;    // set 3 kbd pins to pullup, one kbd pin to out and leave I2C alone...
}
static void inline PORTDSET(uint8_t p) { PORTD|=p; }
static void inline PORTDCLEAR(uint8_t p) { PORTD&=~p; }
static void inline PORTDTOGGLE(uint8_t p) { PORTD^= p; }
static void inline PORTBSET(uint8_t p) { PORTB|=p; }
static void inline PORTBCLEAR(uint8_t p) { PORTB&=~p; }
static uint8_t inline PORTBGET() { return PINB; }
static void inline PORTBPULLUP(uint8_t pin) { PORTB|= pin; DDRB&= ~(pin); }
static void inline PORTBOUT(uint8_t pin) { PORTB|= pin; DDRB|= (pin); }
static void portBWritePin(int8_t pin, int8_t v) { PORTB= (PORTB&(~(1<<pin)))|(v<<pin); }
static void portCWritePin(int8_t pin, int8_t v) { PORTC= (PORTC&(~(1<<pin)))|(v<<pin); }
static uint8_t portCRead() { my_delay_us(1); return PINC; }

// Kbd matrix (3*3)
// static uint8_t const kbdr0= 12, kbdr1= 11, kbdr2= 17; // rows are output. high by default to match the pullups
// static uint8_t const kbdc0= 14, kbdc1= 15, kbdc2= 16; // columns are input, pullup
// Sorry, I have made various PCB with slightly different kbd configurations...
static uint16_t kbdValue()
{
    uint16_t keys;
    #ifndef WEIRED_KBD
        portBWritePin(3, 0); keys= (~portCRead())&0x7; portBWritePin(3, 1); 
        portBWritePin(4, 0); keys|= ((~portCRead())&0x7)<<3;  portBWritePin(4, 1); 
        portCWritePin(3, 0); keys|= uint16_t((~portCRead())&0x7)<<6;  portCWritePin(3, 1); 
    #else // case for erarly prototpyes...
        portBWritePin(3, 0); keys= ((~portCRead())&0x7)<<3; portBWritePin(3, 1); 
        portBWritePin(4, 0); keys|= ((~portCRead())&0x7);  portBWritePin(4, 1); 
        portCWritePin(3, 0); keys|= uint16_t((~portCRead())&0x7)<<6;  portCWritePin(3, 1); 
    #endif
    return keys;
}

static void reboot()
{ // Due to bootloader issues, and some other stuff that I do not understand, you need to make sure that no key is pressed when doing a reboot. And watchdog does not work...
    while (kbdValue()!=0);
    udelay(10000);
    void (*rstfunc)()=0;
    rstfunc();
}

class CSerial { public:
	// interrupt driven serial class. 700 bytes smaller than the standard Serial class...
	// always 38400 bauds, 64bytes buffers
	static uint8_t const BUFFER_SIZE= 64;
	static volatile char rxBuffer[BUFFER_SIZE];
        static uint8_t rxHead= 0, rxTail= 0;
	static volatile char txBuffer[BUFFER_SIZE];
	static uint8_t txHead= 0; static uint8_t volatile txTail= 0;

	// USART Receive Complete interrupt. i.e: data in
	static ISR(USART_RX_vect) 
	{
	  char c= UDR0;
	  uint8_t nextHead= (rxHead+1) & (BUFFER_SIZE-1);
	  if (nextHead==rxTail) return;  // Buffer full
	  rxBuffer[rxHead]= c; rxHead= nextHead;
	}
	// USART Data Register Empty interrupt. I.e: ready to send next byte
	static ISR(USART_UDRE_vect) 
	{
          uint8_t ttxTail= txTail;
	  if (txHead==ttxTail) { UCSR0B&= ~(1<<UDRIE0); return; } // Nothing to send, disable UDRE interrupt
	  UDR0= txBuffer[ttxTail];
	  txTail= (ttxTail+1) & (BUFFER_SIZE-1);
	}
    static void begin() 
    {
      cli(); // Disable global interrupts
      UBRR0H= 0; UBRR0L= 51; UCSR0A= 2; UCSR0C= 6; //38400 bauds
      UCSR0B= 0b00011000 | (1 << RXEN0) | (1 << TXEN0) | (1 << RXCIE0); // enable rx, tx and irqs
      sei(); // Enable global interrupts
    }
	static int16_t read() 
	{
	  if (rxHead==rxTail) return -1; // No data
	  char c= rxBuffer[rxTail];
	  rxTail= (rxTail+1) & (BUFFER_SIZE-1);
	  return c;
	}
	static void print(char c) // add to send buffer and send as soon as possible
	{
	  uint8_t nextHead= (txHead+1) & (BUFFER_SIZE-1);
	  while (nextHead==txTail); // Wait if buffer is full
	  txBuffer[txHead]= c; txHead= nextHead;
	  UCSR0B|= 1<<UDRIE0; 	  // Enable UDRE interrupt
	}
    static void print(char const *c) { while (*c!=0) print(*c++); } // Add string in output buffer..
	// on esp32 writes only send on a flush.
	static void inline flush(char c) { print(c); }
} Serial;

namespace Time {
    uint32_t t= 0; // counter which incremented every 1/4 of a second
    void begin()
    {
        TCCR1A= 0; // no output on compare match, normal, 0 to ffff count
        TCCR1B= 3; // normal count, clock at 1/64th of 16mhz so 4 us per tick, give 65536*4us = 1/4s for a timer overflow...
        TCCR1C= 0; // no output compares...
        OCR1AH= OCR1AL= OCR1BH= OCR1BL= 0; // output compares at 0 as not used
        ICR1H= ICR1L= 0; // same for input captures
        TIMSK1= 0; // no interrupts 
    }
    uint32_t unow() // now in microseconds. But with 4 microsecond precision only...
    {
        // TIFR1 bit 0 is high on overflow of 16 bit timer. happends 4 times per second, so no chances to miss one case
        if ((TIFR1&1)!=0) { TIFR1= 1; t+= 4; } // risk of TIFR1 off here and ticking before the read of TCNT1L... but more than unlikely. and in all cases would just end up giving time in the past for a tick, no issue
        uint8_t l= TCNT1L;
        uint8_t h= TCNT1H;
        return (t<<16)|(uint32_t(h)<<10)|(uint16_t(l)<<2);
    }
    uint32_t mnow() // now in milliseconds. Not used here...
    {
        if ((TIFR1&1)!=0) { TIFR1= 1; t+= 4; } // This happens every 260ms at one 64th divider...so no chances to loose one...
        uint8_t h= TCNT1H;
        return (t<<6)|h;
    }
};

 #if defined(HASADC) && defined(TMC)
namespace CADC {
    void begin()
    {
        PRR&= ~1; // makes sure ADC is on in power reduction
        ADMUX= 0b01100111;  // ref=vcc, A7
        ADCSRB= 0b00000000; // comparator off, free running mode
        ADCSRA= 0b11100111; // enable, start conversion, auto trigger, no_interrupt, irq disable, 128 clock speed
    }
    uint8_t inline next() { return ADCH; }
};
#else
    #undef HASADC // for safety, no ADC if no TMC...
#endif

#define IRAM_ATTR // esp32 thing... not used here
#undef HASGPS     // just making sure! as there is no GPS in __AVR__ mode..
static void sendBNO() {}
static void execBNO(uint32_t i) {}



#elif !defined(PC) // if __AVR__ is not defined, AND PC is not defined... then the only option left is ESP. PC gets defined in the PC source code and __AVR__ in the Arduino system...
// Note that some of the ESP specific code is in main.cpp. Except a couple of things like keyboard that need the key definitions...
#define ESP

#ifndef  HASADC
    #ifndef HARMONIC_MAIN
        // ESP23 C3 pin Layout
        // pins 5,6,7: kbd rows top, mid, bottom
        // pins 8,9: SLC, SDA
        // pins 10,20,21; kbd col left, mid, right
        // pin 4: stepper serial
        // pins 3, 2, 0: stepper step (ra, dec, foc)
        // pin 1: stepper dir (dec)
        static const int8_t raDirPin    = -1; 
        static const int8_t decDirPin   = -1; // it's wired, but we won't use it as tmc react strangely if you use it with rs232
        static const int8_t focDirPin   = -1; 
        static const int8_t raStepPin   = 0, raUartAddr= 3; 
        static const int8_t decStepPin  = 2, decUartAddr= 1;
        static const int8_t focStepPin  = 3, focUartAddr= 2; 
        static const int8_t motorSerialRa = 4;
        static const int8_t motorSerialDec = 4;
        static const int8_t motorSerialFocus = 4;
        static const int8_t krt= 5, krm= 6, krb= 7, kcr= 10, kcl= 20, kcm= 21;
        static const gpio_num_t LCD_SLC= GPIO_NUM_8;
        static const gpio_num_t LCD_SDA= GPIO_NUM_9;
    #else // Harmonic board system
        static const int8_t raDirPin    = -1; 
        static const int8_t decDirPin   = -1;  // we won't use it as tmc react strangely if you use it with rs232
        static const int8_t focDirPin   = -1; 
        static const int8_t raStepPin   = 0; 
        static const int8_t decStepPin  = 1;
        static const int8_t focStepPin  = 3; 
        static const int8_t motorSerialRa = 4, raUartAddr= 0;
        static const int8_t motorSerialDec = 4, decUartAddr= 1;
        static const int8_t motorSerialFocus = 4, focUartAddr= 2;
        static const gpio_num_t LCD_SLC= GPIO_NUM_2; // unused in reality
        static const gpio_num_t LCD_SDA= GPIO_NUM_2;
    #endif
#else // in V2 or 3 of the board we use the ADC to handle the keyboard and monitor power supply
    #ifndef RED_BOARD
        static const int8_t raDirPin    = -1; 
        static const int8_t decDirPin   = -1;  // we won't use it as tmc react strangely if you use it with rs232
        static const int8_t focDirPin   = -1; 
        static const int8_t raStepPin   = 5; 
        static const int8_t decStepPin  = 7;
        static const int8_t focStepPin  = 8; 
        static const int8_t motorSerialRa = 21, raUartAddr= 1;
        static const int8_t motorSerialDec = 21, decUartAddr= 2;
        static const int8_t motorSerialFocus = 21, focUartAddr= 0;
        static const gpio_num_t LCD_SLC= GPIO_NUM_10;
        static const gpio_num_t LCD_SDA= GPIO_NUM_0;
    #else
        static const int8_t raDirPin    = -1; 
        static const int8_t decDirPin   = -1;  // we won't use it as tmc react strangely if you use it with rs232
        static const int8_t focDirPin   = -1; 
        static const int8_t raStepPin   = 5; 
        static const int8_t decStepPin  = 7;
        static const int8_t focStepPin  = 8; 
        static const int8_t motorSerialRa = 6, raUartAddr= 1;
        static const int8_t motorSerialDec = 6, decUartAddr= 2;
        static const int8_t motorSerialFocus = 6, focUartAddr= 0;
        static const gpio_num_t LCD_SLC= GPIO_NUM_20;
        static const gpio_num_t LCD_SDA= GPIO_NUM_21;
        static const int8_t GPSPin= 10;
    #endif
#endif

#include "hal/gpio_types.h"
#include "soc/gpio_reg.h"
#include "soc/io_mux_reg.h"
#include "soc/soc.h"
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
int main() 
{
    setup();
    timer2_init_10kHz();
    while (true) loop();
}
#endif
#endif

#ifdef ALPACA
static bool canGoThere(int32_t ra, int32_t dec)
{
    if ((CSavedData::savedData.invertAxes&0x10)==0) return true;
    // Calculate target ra/dec motor positions in hours and degrees with 0,90 vertical pointing north
    int32_t mid= (MRa.minPosReal+MRa.maxPosReal)/2;
    float raf= -(mid-int32_t(ra))/3600.0f;
    if (scopeWest()) raf+= 12.0f;
    // Now, get az/alt based on these positions which correspond to 6am LST
    float alt, az; raDecToAltAz(raf, dec/3600.0f, 6.0f, CSavedData::savedData.Latitude/36000.0f, &alt, &az);
    return alt>=0.0f;
}
static void stopIfUnder()
{
    if ((CSavedData::savedData.invertAxes&0x10)!=0 && MRa.sideralMove!=0 && !canGoThere(MRaposInReal(), MDec.posInReal())) 
        CSavedData::savedData.initUncountedStep2(0);
}

#endif

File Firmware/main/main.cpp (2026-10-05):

#pragma GCC diagnostic ignored "-Wmissing-field-initializers"
#pragma GCC diagnostic ignored "-Wmisleading-indentation"

#define TMC // always defined in ESP mode...
//#define HARMONIC_MAIN // Used for harmonic dual board system... will cut off UI

#include "sdkconfig.h"
#include "esp_log.h"
#include "freertos/FreeRTOS.h"
#include "freertos/task.h"
#include "driver/gpio.h"
#include "esp_task_wdt.h"
#include "esp_wifi.h"
#include "esp_netif.h"
#include <math.h>
#include <string.h>


class CSerial;
void sendBNO(CSerial &serial);
void execBNO(uint32_t i, uint32_t j);


#include "../eqControl_Ino/eqControl_Ino.ino"
#include "BLE.h"

#ifdef HARMONIC_MAIN // Used for harmonic dual board system... will cut off UI
class CHarmonicSerial : public CSerial { public:
    static void begin() 
    {
        const uart_config_t uart_config = { .baud_rate= 9600, .data_bits= UART_DATA_8_BITS, .parity= UART_PARITY_DISABLE, .stop_bits= UART_STOP_BITS_1, .flow_ctrl= UART_HW_FLOWCTRL_DISABLE };
        uart_driver_install(UART_NUM_0, 1024*2, 1024*2, 0, NULL, 0);
        uart_param_config(UART_NUM_0, &uart_config);
        uart_set_pin(UART_NUM_0, 5, 6, -1, -1); // use pins 5 and 6 for send/recv
    }
    int16_t read() override
    { 
        char c;
        int len= uart_read_bytes(UART_NUM_0, &c, 1, 20 / portTICK_PERIOD_MS);
        if (len!=1) return -1; return c;
    }
    int read(uint8_t *d, int size) override
    { 
        return  uart_read_bytes(UART_NUM_0, (char*)d, size, 1000 / portTICK_PERIOD_MS);
    }
    void flush(char const *s, int size) override { uart_write_bytes(UART_NUM_0, s, size); }
} harmonicSerial;
TSerialContext harmonicSerialContext;
static void harmonicSerialTask(void*)
{
    harmonicSerial.begin();
    while (true)
    {
        uint8_t d[64]; int l= harmonicSerial.read(d, sizeof(d)); // blocking...
        if (l>0) processSerial((char*)d, l, harmonicSerialContext, harmonicSerial);
    }
}
#endif


static void UITask(void*)
{
    display.begin();
    while (true) { vTaskDelay(1); doUI(); } // minimum delay to give other task time to do something
}
static void SerialTask(void*)
{
    while (true)
    {
        uint8_t d[64]; int l= Serial.read(d, sizeof(d)); // blocking...
        if (l>0) processSerial((char*)d, l, serialContext, Serial);
    }
}
static bool IRAM_ATTR stepperTick(gptimer_handle_t timer, const gptimer_alarm_event_data_t *edata, void *user_data)
{
    uint32_t now= Time::unow();
    MRa.step(now); MDec.step(now); MFocus.step(now); 
    return pdFALSE;
}

#include "localAlpaca.h"

	static void wifi_event_handler(void* arg, esp_event_base_t event_base, int32_t event_id, void* event_data)
	{
	    if (event_base == WIFI_EVENT && event_id == WIFI_EVENT_STA_START) esp_wifi_connect();
	    else if (event_base == WIFI_EVENT && event_id == WIFI_EVENT_STA_DISCONNECTED) { esp_wifi_connect(); ipaddr = 0; } 
	    else if (event_base == IP_EVENT && event_id == IP_EVENT_STA_GOT_IP) ipaddr = ((ip_event_got_ip_t*) event_data)->ip_info.ip.addr;
	    else if (event_base == WIFI_EVENT && event_id == WIFI_EVENT_AP_START) ipaddr= 0x0104A8C0;
	}

	static wifi_init_config_t wificfg;
void startWifi(const char *net, const char *pass, const char *hostname, bool accessPoint)
{
    esp_err_t ret = nvs_flash_init();
    if (ret == ESP_ERR_NVS_NO_FREE_PAGES || ret == ESP_ERR_NVS_NEW_VERSION_FOUND) { ESP_ERROR_CHECK(nvs_flash_erase()); ret = nvs_flash_init(); }
    ESP_ERROR_CHECK(ret);

    ESP_ERROR_CHECK(esp_netif_init());
    ESP_ERROR_CHECK(esp_event_loop_create_default());

    if (accessPoint) esp_netif_set_hostname(esp_netif_create_default_wifi_ap(), hostname);
    else esp_netif_set_hostname(esp_netif_create_default_wifi_sta(), hostname);

    wificfg = WIFI_INIT_CONFIG_DEFAULT(); ESP_ERROR_CHECK(esp_wifi_init(&wificfg));

    ESP_ERROR_CHECK(esp_event_handler_instance_register(WIFI_EVENT, ESP_EVENT_ANY_ID, &wifi_event_handler, NULL, NULL));
    ESP_ERROR_CHECK(esp_event_handler_instance_register(IP_EVENT, IP_EVENT_STA_GOT_IP, &wifi_event_handler, NULL, NULL));

    wifi_config_t wifi_config; memset(&wifi_config, 0, sizeof(wifi_config));

    if (!accessPoint) 
    {
        wifi_config.sta.threshold.authmode = pass[0]!=0 ? WIFI_AUTH_WPA2_PSK : WIFI_AUTH_OPEN;
        strncpy((char *)wifi_config.sta.ssid, net, sizeof(wifi_config.sta.ssid) - 1);
        strncpy((char *)wifi_config.sta.password, pass, sizeof(wifi_config.sta.password) - 1);
        wifi_config.sta.pmf_cfg.capable = true;
        wifi_config.sta.pmf_cfg.required = false;
        ESP_ERROR_CHECK(esp_wifi_set_mode(WIFI_MODE_STA));
        ESP_ERROR_CHECK(esp_wifi_set_config(WIFI_IF_STA, &wifi_config));
    } else {
        strncpy((char*)wifi_config.ap.ssid, net, sizeof(wifi_config.ap.ssid)-1);
        strncat((char*)wifi_config.ap.ssid, "_AP", sizeof(wifi_config.ap.ssid)-1);
        wifi_config.ap.ssid_len= strlen(net)+3;
        wifi_config.ap.channel = 6;
        wifi_config.ap.max_connection = 4,
        wifi_config.ap.authmode = WIFI_AUTH_OPEN, // WIFI_AUTH_WPA2_PSK,
        wifi_config.ap.pmf_cfg.required = true;
        ESP_ERROR_CHECK(esp_wifi_set_mode(WIFI_MODE_AP));
        ESP_ERROR_CHECK(esp_wifi_set_config(WIFI_IF_AP, &wifi_config));
    }

    ESP_ERROR_CHECK(esp_wifi_start());
}

void altAzToRaDec(float alt, float az, float lat_rad, float lst, float &ra, float &dec) 
{
    // 2. Conversion Alt/Az -> Dec / Hour Angle (HA)
    // float lat_rad = lat * (M_PI / 180.0f);
    // Calcul de la Déclinaison (Dec)
    float sin_dec = sinf(alt) * sinf(lat_rad) + cosf(alt) * cosf(lat_rad) * cosf(az);
    float tdec = asinf(sin_dec);
    // Calcul de l'Angle Horaire (HA)
    float cos_ha = (sinf(alt) - sinf(lat_rad) * sinf(tdec)) / (cosf(lat_rad) * cosf(tdec));
    // Sécurité pour les erreurs d'arrondi de floating point
    if (cos_ha > 1.0f) cos_ha = 1.0f; if (cos_ha < -1.0f) cos_ha = -1.0f;
    float ha = acosf(cos_ha);
    // Si l'Azimuth est à l'Est du méridien, l'HA est négatif
    if (sinf(az) > 0.0f) ha = 2.0f * M_PI - ha;
    // 3. Conversion HA -> Right Ascension (RA)
    float ha_hours = ha * (180.0f / M_PI) / 15.0f;
    float tra = lst - ha_hours;
    // Normalisation de la RA entre 0 et 24h
    while (tra < 0.0f) tra += 24.0f;
    while (tra >= 24.0f) tra -= 24.0f;
    // write output...
    ra= tra;
    dec = tdec * (180.0f / M_PI);
}

#include "bno.cpp"
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

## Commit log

2025-11-18 First checkin
    This is a first dump of files.
    This version has the arduino FW (tested on drv2285), the ascom drivers (compilation not tested, it will be the next step)
2025-11-18 Binary for the Ascom drivers
    Verified that the Ascom driver compiled and released them here
2025-11-20 Improve speed/timing
    They was some issues in quantization which have been fixed here and that were causing some strange behaviors.
    Also quantization was taking over 10% of CPU time, so I reduced it to once every 10ms and now it's around 1%
    [eqControl_Ino.ino]
2025-11-21 Change motor steppers to now use IRQ
    With this new version steps are issued at 10Khz using IRQ.
    It removes issues with harsh things when LCD display was happening in the previous version.
    [eqControl_Ino.ino]
2025-12-02 This version adds support for esp32
2025-12-02 UI cleanup on ascom driver
2025-12-04 add mechanical files
    [eq3_5 dec.dxf, eq5_ra.dxf]
2025-12-08 Satelite track changes, telescope view change
    Make a satelite track window that shows where it is, corrections and speeds.
    Make catalog system work better and allow click and goto on the sky map
2025-12-09 rework spirale to be a spirale. small wifi update
    [Alpaca.cpp, Alpaca.h, eqControl_Ino.ino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]
2025-12-11 minor tweaks, fix alpaca axes rates
    [Alpaca.cpp, eqControl_Ino.ino, main.cpp]
2025-12-18 change driver name
2026-01-02 Fix sideral speed issues, fix parking not working well, add com reconnect on usb errors, fix issues with uncounted steps on heavy geared mounts,
    [eqControl_Ino.ino]
2026-01-04 Add ability to disable auto flip in settings
    [eqControl_Ino.ino, windowsVersion.cpp]
2026-01-07 Fix bugs in relation with obs conditions in ascom driver, change the way guiding rates are stored, work on GPS to get signal continiously, change sdk setup to enable 2 uarts,
    [eqControl_Ino.ino, main.cpp, windowsVersion.cpp]
2026-01-07 fix AP setup checkbox, get GPS data if present, esp AP and gps was not displayed on controler ui, now continiously update gps
    [eqControl_Ino.ino, main.cpp]
2026-01-15 Fix some ascom issues
    [windowsVersion.cpp]
2026-03-04 Add focus position save fix windows version build fix utc date warnings in alpaca add BNO support in ascom Driver fix axes rates issues in alpaca
    [Alpaca.cpp, Alpaca.h, eqControl_Ino.ino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]
2026-05-25 fix guide rates, add phd2 reguide delay
    [Alpaca.cpp, Alpaca.h, eqControl_Ino.ino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]
2026-06-02 get temp from BNO if possible make BNO work on device!
2026-06-03 work on adding BNO support. at this point not working at a functional level, but working at a HW sensor level
    [Alpaca.cpp, Alpaca.h, main.cpp]
2026-06-04 move to IMU mode for BNO055
2026-07-01 Tentative work with BNO. Does not work. To be redone :(
    [main.cpp]
2026-10-01 rework satellite tracking windows with better graphics, meridian flip display and prevision paths rework to use worker threads instead of call backs on timers add BT support add RA axis resync featur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
    add horizon limits in HW
    add backlash in RA management
    add more moving speeds
    add goto puts preference on east side
    [Alpaca.cpp, Alpaca.h, bno.cpp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]
2026-10-05 add partition table move to different BLE system start working on Harmonic fix minor BLE issues
    [partitions.csv]
2026-11-09 First checkin of new version which is not derived from the Arduino system
